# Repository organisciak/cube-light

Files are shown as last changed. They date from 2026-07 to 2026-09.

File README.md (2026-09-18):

# cube-light

**A 10×10×10 music reactive LED cube.** One thousand addressable pixels, an
ESP32 microcontroller that lives inside the cube, a phone-friendly console. And 3D snake!

Best way to understand it - try it in browser: <https://cube.porg.dev>

| | |
|---|---|
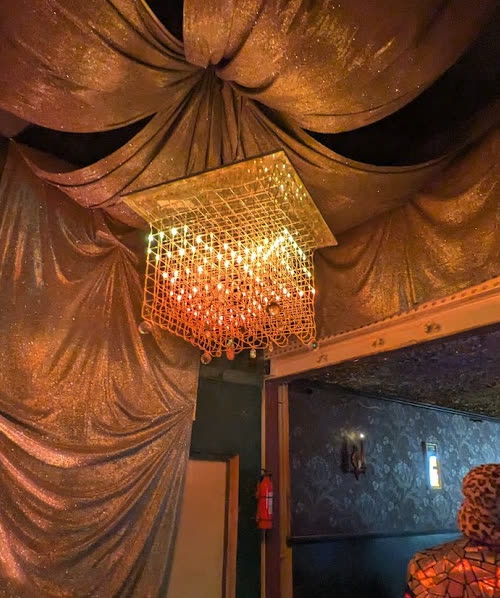
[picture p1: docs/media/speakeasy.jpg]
The cube hanging in the speakeasy
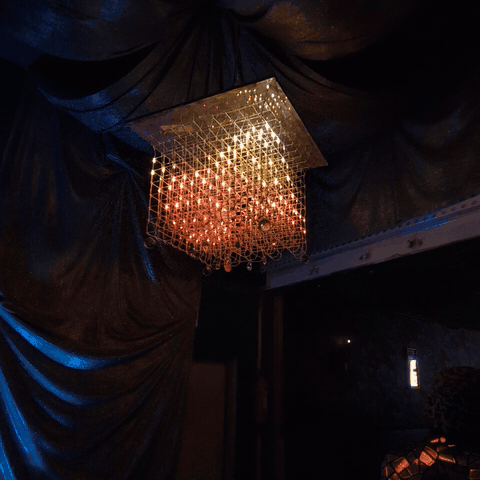
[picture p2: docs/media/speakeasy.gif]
The cube reacting to music in the speakeasy
|  |  |

It went to the playa in 2026 and ran for a week off in our camp's [speakeasy](https://www.instagram.com/p/DdFiTw2u4o9/).
[Here's a minute of it](docs/media/cube-light-playa.mp4) lit up at home and mid-build.
This repo is everything needed to build one: the firmware, the console, the
calibration tools, and (soon) the physical build notes. The firmware is all custom, which allows much more interesting music-reactivity and varied patterning.

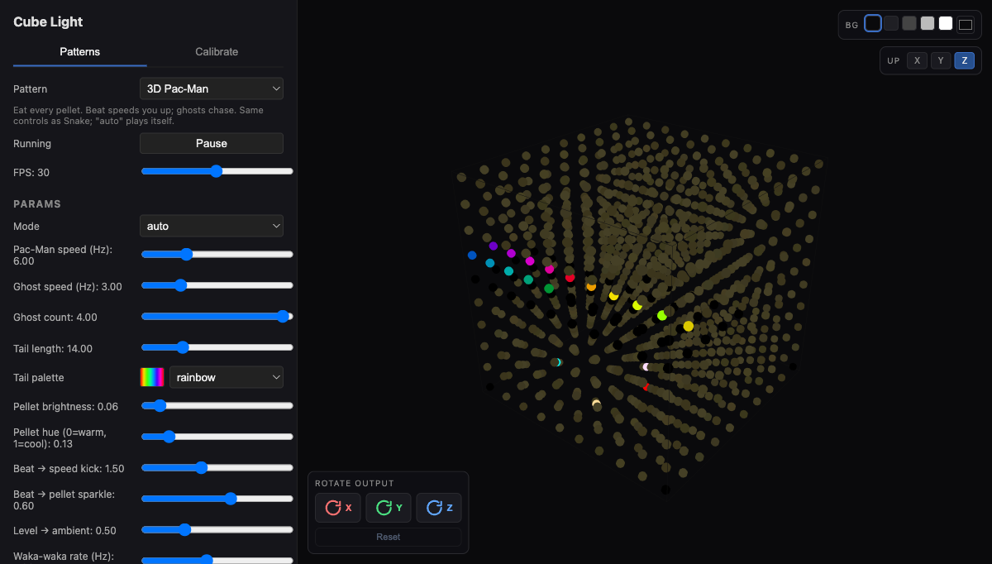
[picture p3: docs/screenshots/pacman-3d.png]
3D Pac-Man playing itself


## What it does

- **28 patterns** written against `(x, y, z)` voxels rather than a strip: wavy
  sheet, rotating planes, rain, comets, storm cloud, spirals, orbiting atoms,
  a tumbling wireframe cube, a first-person neon rail ride, a synesthetic
  tunnel, a double helix, TV static, fireworks, a 3D text marquee, album art
  on all four faces, and more.
- **Music-reactive.** An onboard mic feeds an FFT, eight log-spaced bands, a
  loudness envelope and a beat detector into every pattern. Patterns choose
  what to do with it: throb, spin faster, spawn ripples, kick the rail.
- **Games.** 3D Snake and 3D Pac-Man with a phone game pad (or they play
  themselves with a BFS solver when nobody is holding the controls).
- **Presets and playlists.** Save any pattern + params + palette as a preset,
  weight it, and let the cube cycle. Curated playlists, shuffle, a demo dwell
  for filming, and a physical button that steps to the next preset.
- **Guest mode.** Anyone who joins the cube's hotspot gets patterns, knobs,
  brightness and the game pad. Settings, Wi-Fi and calibration stay behind an
  owner password. Flip one switch and the hotspot password is the only gate.
- **Home Assistant.** MQTT discovery publishes a light, pattern and preset
  selects, playlist transport, and a text entity. Song titles and album art
  from your media player show up on the cube. See
  [docs/home-assistant.md](docs/home-assistant.md).
- **Per-parameter modulation.** Any numeric knob can ride an LFO or a random
  walk, so a static preset keeps evolving.
- **Calibration that solves your wiring.** Light one LED, say where it is,
  repeat a few times; the cube works out axis order, flips and serpentine
  runs from 192 candidate layouts. Snipped-LED compensation keeps geometry
  correct after you cut a dead pixel out of a chain.
- **Runs on ~$20 of controller.** A Gledopto WLED controller straight out of
  the box, or any classic ESP32 plus an I2S microphone.

| | |
|---|---|
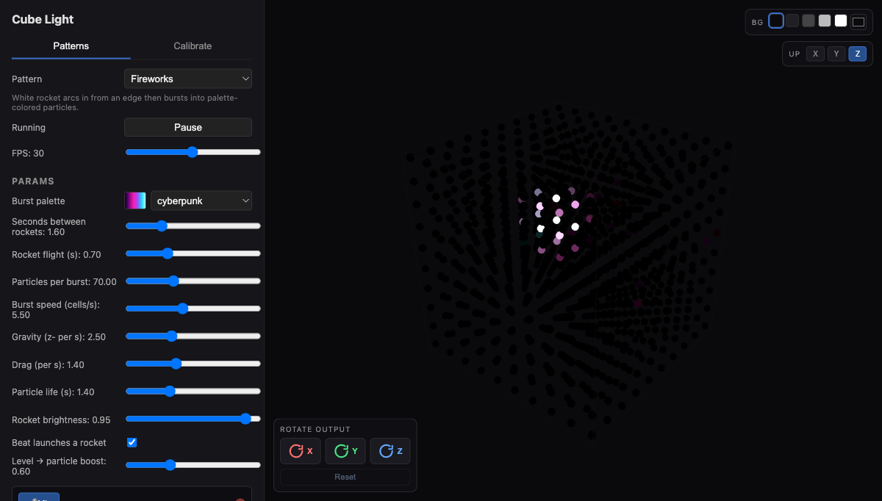
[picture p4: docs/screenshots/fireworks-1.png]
Fireworks
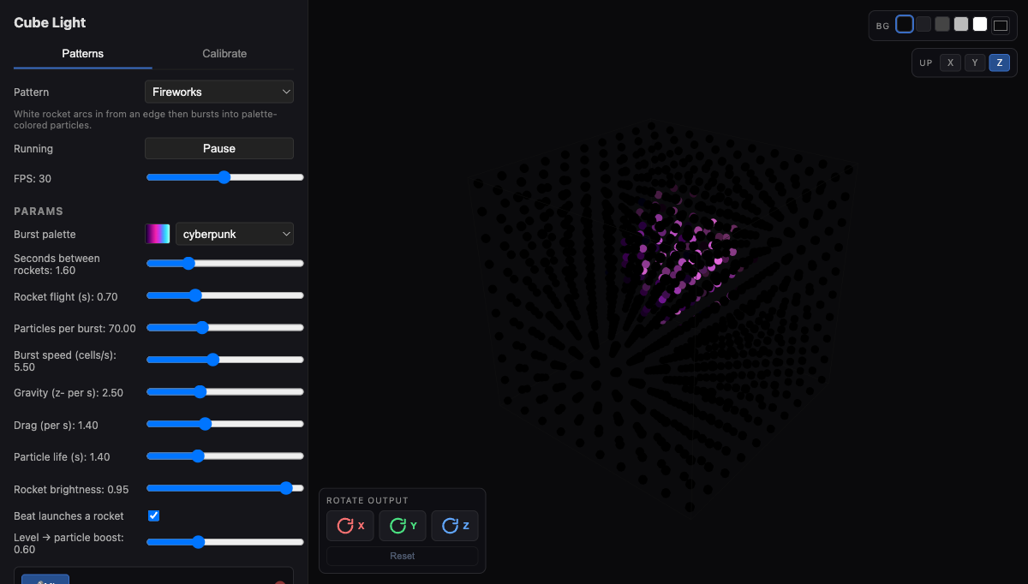
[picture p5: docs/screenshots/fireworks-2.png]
Fireworks, cyberpunk palette
|  |  |
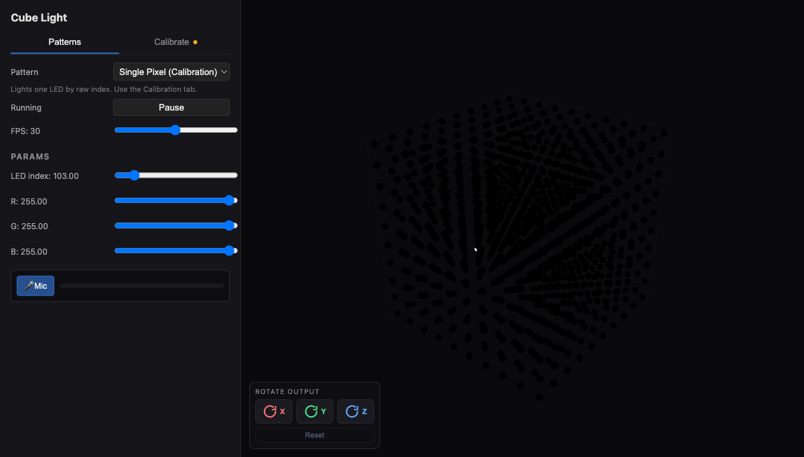
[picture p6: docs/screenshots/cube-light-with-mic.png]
Calibration lighting one LED
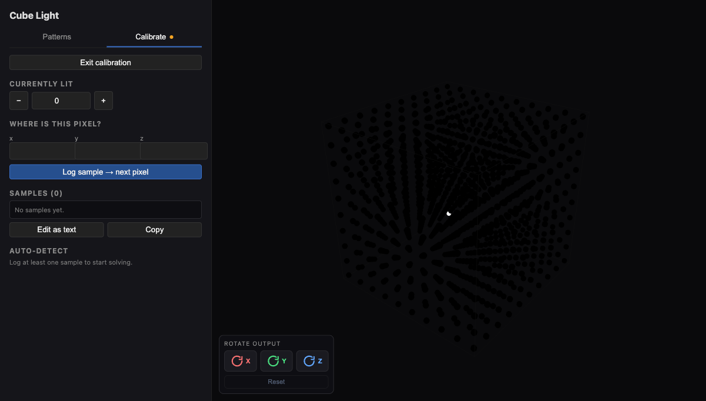
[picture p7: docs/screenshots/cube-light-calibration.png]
Calibration samples
|  |  |

*Screenshots are from the retired browser preview. For the real thing without
a cube, the [browser simulator](https://cube.porg.dev/) runs the
firmware's own pattern code (compiled to WebAssembly) and draws it like a
1984 CRT logo card.*

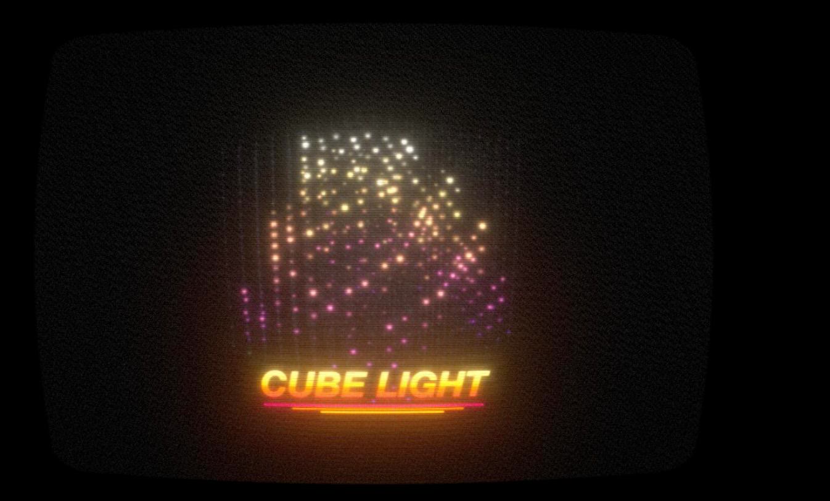
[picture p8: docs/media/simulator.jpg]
The simulator: firmware patterns through a CRT shader


## Building one

Three parts: a cube of LEDs, a controller, and this firmware.

### 1. The cube

- **1000 × 12 V WS2811 "seed" pixels**, wired as two chains of 500. Seed
  pixels (the tiny ones on thin wire, not 12 mm bullets) matter: the cube
  reads as points of light in air rather than a wall of bulbs. These are
  [the RGB ones I used](https://www.aliexpress.us/item/3256807315916397.html);
  BTF-Lighting, Ray Wu and the usual AliExpress storefronts all sell similar
  1000-pixel strings under *WS2811 12V seed pixel string*.

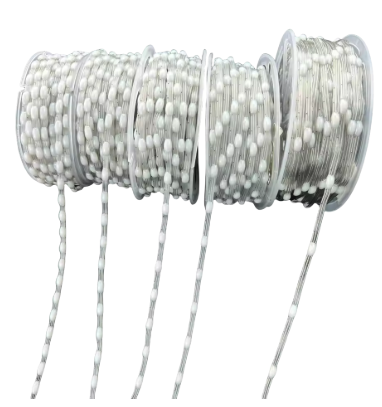
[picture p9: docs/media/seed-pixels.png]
WS2811 seed pixel strings on reels
  

    - Almost certainly, SK6812-style lights with their own white (RGBW) would look better, for a bit more money - here's a listing of ones I've used elsewhere [https://www.aliexpress.us/item/3256805834823384.html]. I haven't tried it with my cube light build, though.
    - If you wanted to do 5V instead of 12V, you'd probably get power dropoff with two runs of 500 leds. Easy enough - just have power injection more frequently. The code would need (tiny) modification if you wanted more than two data lines, though.
- A frame that holds 10 vertical strings of 100 pixels each in a 10×10 grid. Any wiring order works because calibration solves it afterwards. I ran it as a long snake that would go top down on one column, then bottom up on the next, etc. This required a bit of code calibration, because the first pixel of the run was at 0,0,0, but the second pixel is 0,0,1, while 0,1,0 was the 10th pixel and 1,0,0 was the 200th. 
    - What didn't work well: version one had two acrylic sheets - top and bottom plane, with holes drilled out and the lights strung through. I'd hoped the weight of the bottom sheet would pull everything down. However, getting the wires taut in between was tricky, and everything looked sloppy.
    - What *did* work: 3D-printed clips, keeping all the planes connected. STLs, OpenSCAD source and print notes are in [`hardware/clips/`](hardware/clips/). I used translucent PETG and the scaffolding clips both kept the shape and didn't obscure the lights, complemented the design with a matrix look.
- A 12 V supply. The firmware's power limiter caps total draw (default 10 A); full white on 1000 pixels would be ~15 A, so the software limiter matters (or just get a big boy supply!).

Build notes, photos and the parts list are in
[docs/build.md](docs/build.md).

### 2. The controller

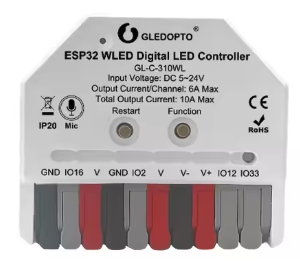
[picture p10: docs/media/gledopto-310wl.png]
Gledopto GL-C-310WL


| Board | Mic | Flashing | Notes |
| --- | --- | --- | --- |
| **Gledopto GL-C-618WL** | onboard PDM | USB-C | The board the project was developed on. This is just a nice enclosure for an ESP-32 with mic and all the things you probably would neglect otherwise (fuse, power relay, step-up). This specific model was probably overkill - don't need the ethernet. Slightly smaller ones that would work from the same company are: GL-C-017WL-D (015 or 016 too) or the GL-C-615WL. I wouldn't expect an ESP8266 to work, I pushed this one pretty far. |
| Gledopto GL-C-310WL | onboard I2S | OTA only (no USB) | Mini version. These are just great to have around for various projects. Don't do the 309, which is mic-less - and the cube is not as exciting without one. I brought a backup to playa on a 309 without realizing it was the wrong one, glad I didn't have to use it! |
| Any ESP32 + INMP441 | I2S | USB | Wire your own; pins are build flags. |

Every board is one `[env:...]` block in
[firmware/platformio.ini](firmware/platformio.ini): LED pins, button, relay,
mic type and pins, mDNS name. Copy one and edit for new hardware.

### 3. The firmware

```bash
cd firmware
pio run -e gledopto618 -t upload      # first flash over USB
pio device monitor -e gledopto618     # 115200 baud
```

The cube comes up as a Wi-Fi hotspot named `cube-light` (password
`cubelight`, change it). Join it, open <http://cube.local/> or
<http://192.168.4.1/>, and pick a pattern. The `/wifi` page joins it to your
home network; after that, wireless updates are available from `/admin`.

No-USB boards (309/310) get their first image through stock WLED's update
page. [docs/flashing-offline.md](docs/flashing-offline.md) is the full
runbook, including recovery and the OTA size ceiling.

## The console

Everything is served from the cube itself, sized for a phone.

- `/` picks patterns (grouped into light patterns, games, and tools), exposes
  each pattern's parameters with hover help, palettes, brightness, the mic
  toggle, the preset sidebar and the playlist transport. Advanced mode reveals
  modulation and the audio-drive caps.
- `/snake` is the game pad. Direction keys are calibrated to the player's
  viewpoint so "up" means up from where you stand.
- `/admin` handles power, wireless update arming, presets import/export and
  the demo dwell. `/leds` sets outputs, color order, snipped-LED compensation
  and the mic channel/squelch. `/calibrate` runs the wiring wizard. `/wifi`
  holds network, passwords, guest mode and the Home Assistant broker.
- `/api/status`, `/api/audio` and friends are plain JSON if you want to
  script it. DNRGB packets on udp/21324 (WLED's realtime protocol) override
  the local pattern, so anything that can drive WLED can drive the cube.

## Running the engine on your computer

The pattern engine is dependency-free C++ shared between the ESP32 build and
a native harness:

```bash
firmware/native/build.sh
firmware/native/build/cube-native rez-tunnel --fake-audio --host 192.168.0.180
```

It streams DNRGB frames to a cube, to stock WLED, or to any receiver that
speaks the protocol. See [firmware/README.md](firmware/README.md) for the
engine layout and how to add a pattern.

## Simulator

**Live at [cube.porg.dev](https://cube.porg.dev/).**
[`simulator/`](simulator/) is the cube in a browser tab: the firmware engine
compiled to WebAssembly, rendered in three.js with phosphor persistence, bloom
and a full CRT pass (scanlines, grille, curvature, aberration, bleed, grain).
Your laptop mic drives the music-reactive patterns through the same band
analysis and beat detector the cube uses, or a synthetic 120 BPM groove does.
It records 5 or 10 second WebM clips, because LED cubes photograph terribly.

```bash
python3 simulator/serve.py   # then open http://127.0.0.1:5277/
```

## Roadmap

- **Build documentation** with more photos and a finished bill of materials.
- ESP-NOW hardware controller for Snake ([docs/controller-plan.md](docs/controller-plan.md)).

Open issues live in the repo's `.beads/` tracker.

## Repo layout

- `firmware/lib/core/` — the pattern engine (pure C++): geometry, palettes,
  params, audio analysis, one file per pattern.
- `firmware/src/` — ESP32 glue: networking, web console, mic capture, presets,
  Home Assistant.
- `firmware/native/` — host harness.
- `hardware/clips/` — the 3D-printed frame clips (STL + OpenSCAD).
- `simulator/` — browser simulator: the engine as WASM + three.js CRT renderer.
- `docs/` — flashing runbook, HA integration, build notes, stock-WLED config
  backups for the boards, screenshots.

The original React + Node prototype that streamed frames to stock WLED is
preserved at git tag `wled-prototype` - once I moved away from that prototyping code, I never looked back, so treat it with a grain of salt.

## License

MIT. See [LICENSE](LICENSE).

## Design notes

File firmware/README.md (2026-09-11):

# cube-light firmware

Standalone brain for the cube: the pattern engine running on the Gledopto
ESP32 itself (GL-C-618WL target). See `docs/on-chip-plan.md` for the full plan.

## Layout

- `lib/core/` — the pattern engine, **pure C++** (no Arduino headers):
  geometry, palettes, color, params, audio analysis, and the patterns
  themselves. Compiles identically for the ESP32 and for the host.
- `src/main.cpp` — ESP32 entry point: WiFi, NeoPixelBus (RMT) LED output,
  DNRGB live-override listener on udp/21324, ArduinoOTA. Pins come from
  `platformio.ini` build flags — check them against stock WLED's settings
  for any new board before first flash.
- `native/` — host harness. Compiles `lib/core` with clang++ and streams
  frames as WLED DNRGB packets, so the exact firmware pattern code can be
  run with zero hardware (point it at a real cube, stock WLED, or a
  DNRGB-speaking simulator).
- `platformio.ini` — ESP32 build config (`pio run -e gledopto618 -t upload`).
- `src/ha_mqtt.h` — Home Assistant bridge (MQTT discovery: light + pattern /
  preset selects + text entity). Configure from `/wifi`; see
  `docs/home-assistant.md` for automations (song titles, album art).

## Running the engine without hardware

```bash
firmware/native/build.sh
firmware/native/build/cube-native wavy-sheet --fake-audio --host 192.168.0.180
```

The harness renders the exact firmware pattern code on your machine and sends
DNRGB packets (udp/21324) to `--host` (default `127.0.0.1`). Any DNRGB receiver
works: a cube running this firmware (its live-override listener takes the
frames), stock WLED with *Receive UDP realtime* on, or a simulator. A
browser-based simulator that receives these frames is planned (see the beads
issue tracker); the retired React preview that used to fill this role lives at
git tag `wled-prototype`.

Harness usage:

```
cube-native [patternId] [key=value ...] [--fps N] [--seconds S] [--fake-audio]
            [--host IP] [--port P]
```

`key=value` pairs map to the pattern's params (`true`/`false` → bool, numbers
→ number, else string), e.g. `cube-native wavy-sheet palette=arctic amp=2`.
Unset params use the defaults from `cube_param_specs.h`.

Caveat: the harness renders with the **default layout**; a receiver with a
calibrated layout active will look scrambled.

## Adding a pattern

1. Copy the closest `pat_*.cpp` and write the render body against
   `PatternCtx` (`cube_pattern.h`): `t`, `dt`, `audio`, `params`, and the
   `setIdx(x,y,z)` voxel index. Params are read with inline defaults
   (`p.num("amp", 1.2f)`).
2. Register it in `cube_patterns.cpp` and add its spec block to
   `cube_param_specs.h` (that block drives the web UI's controls).
3. `firmware/native/build.sh && cube-native <id> --fake-audio` against a cube
   or simulator, then an on-cube pass — LED cubes read very differently from
   a screen (sparse, high-contrast designs win).

### Pattern param specs

`lib/core/cube_param_specs.h` (parameter names/types/ranges/defaults for the
web UI) is **hand-maintained and authoritative** — edit it directly when
adding or changing a pattern's params.

Two shared blocks get spliced into pattern spec arrays instead of being
retyped, so the same knob means the same thing everywhere:

- `CUBE_THROB_SPECS(defaultDepth)` — the beat-driven brightness throb
  (`cube_throb.h`): `throbDepth` / `throbAttack` / `throbRelease`.
- `CUBE_PALETTE_SOLO_SPECS` — single-color palette mode (`cube_palettes.h`):
  `paletteSolo` / `soloSpeed`. On every pattern that has a `palette` param.

### Single-color ("solo") palettes

With `paletteSolo` on, a palette stops being a spatial gradient and becomes a
journey: the whole pattern takes **one** palette color per frame and drifts
through the palette at `soloSpeed` passes/second. Picking `rainbow` walks the
cube through the colors of the rainbow one at a time; `fire` walks red →
orange → yellow → white and back.

It lives in the palette layer — `resolvePalette(name, params, now)` bakes the
drifting position into the `PaletteRef` and `samplePalette()` ignores the
per-voxel `t` — so every palette-bearing pattern gets it for free. Sampled
colors are renormalized to full value in this mode, since most gradients ramp
out of black and a solo sweep through that end would just dim the cube.

## Snipped-LED compensation

Burnt-out LEDs get physically cut off a chain; without compensation, a snip at
the *start* of an output shifts every surviving LED's data by that many
positions and scrambles the calibrated geometry. The `/leds` page (and
`/api/ledcfg` args `skip1/trim1/skip2/trim2`, persisted in NVS) records how
many LEDs each output lost from its start/end: `show()` then feeds each data
slot the logical LED that physically sits there, so patterns stay
geometry-correct and the snipped spots simply go dark. End trims are recorded
for completeness but need no shift.

To rehearse on an intact cube, the same page has a snip **simulator**
(`/api/ledsim`, runtime-only — reboot clears it): it makes a chain behave as
if N LEDs were cut. Simulate N, watch the pattern slide out of place, set
"snipped from start" to N, and it should snap back with N dark spots.

## Hardware gotchas (learned the hard way)

- **Arduino core 2.x WiFi crash-loop on mesh networks.** The stock PlatformIO
  `espressif32` platform is frozen at arduino-esp32 2.x (IDF 4.4), whose WiFi
  stack dies with `InstructionFetchError` in `sta_recv_mgmt` /
  `offchan_recv_action` when a router sends 802.11k/v roaming action frames —
  i.e., the instant it joins a mesh network as a client. AP mode never
  triggers it (nobody sends the cube those frames), which made it look like
  "joining WiFi broke the cube." Fixed by the pioarduino platform pin in
  platformio.ini (arduino-esp32 3.x / IDF 5.5).
- **Startup ordering matters.** Network services (mDNS/OTA/UDP/HTTP) and the
  mic start from `startNetServices()` only after an interface is up.
- **GPIO18 relay must be HIGH** or the LED string has no power (looks exactly
  like a data-wiring failure).
- Debug flags for bisecting on-hardware problems:
  `-DCUBE_LED_BISECT_DISABLE`, `-DCUBE_MIC_BISECT_NO_I2S`,
  `-DCUBE_MIC_BISECT_NO_TASK`.

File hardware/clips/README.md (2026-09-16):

# Frame clips (3D-printed)

The original cube used the weight of the hanging strings and a bottom clear acrylic plate to keep the planes aligned - it didn't work well.

The improvement was to 3D print translucent combs of spaced clips to add a matrix scaffolding to the cube.
Each comb is a thin bar with a snap clip every 50 mm; the clips grab the string's wire between beads, and the beads themselves
(bigger than any pocket) act as position stops. Stack combs across rows and
columns and the strings hold each other square. Translucent PETG nearly
vanishes when the cube is lit, and what you do see reads as a matrix scaffold.

The combs had either 5 or 6 clips on them - my 3d printer (nor most?) doesn't have a bed big enough to print a single comb that spans the full cube widths, so instead I had LEDs 1-5 clipped, then 5-10.

| File | Clips | Length | Shape |
| --- | --- | --- | --- |
| `strut-u24.stl` | 5 | 204 mm | U: pockets open sideways off the bar |
| `strut-c24.stl` | 5 | 210 mm | C: the bar is the lower jaw, a barbed finger closes over the wire |
| `strut6-u24.stl` | 6 | 254 mm | U, six clips |
| `strut6-c24.stl` | 6 | 260 mm | C, six clips |

All are 2.4 mm thick with a 1.1 mm pocket (sized for the squishy stranded
seed-pixel wire, 4.8 × 1.3 mm) and a 1.2 mm bar.

| U clip | C clip |
| --- | --- |
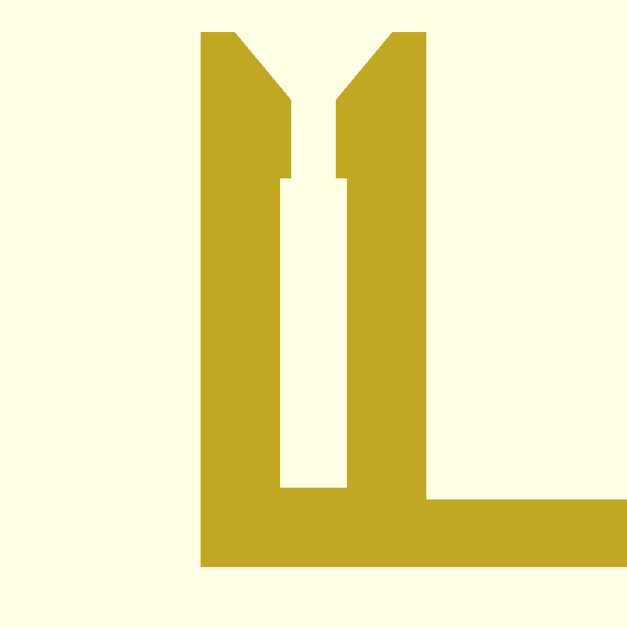
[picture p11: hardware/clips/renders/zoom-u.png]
U clip station
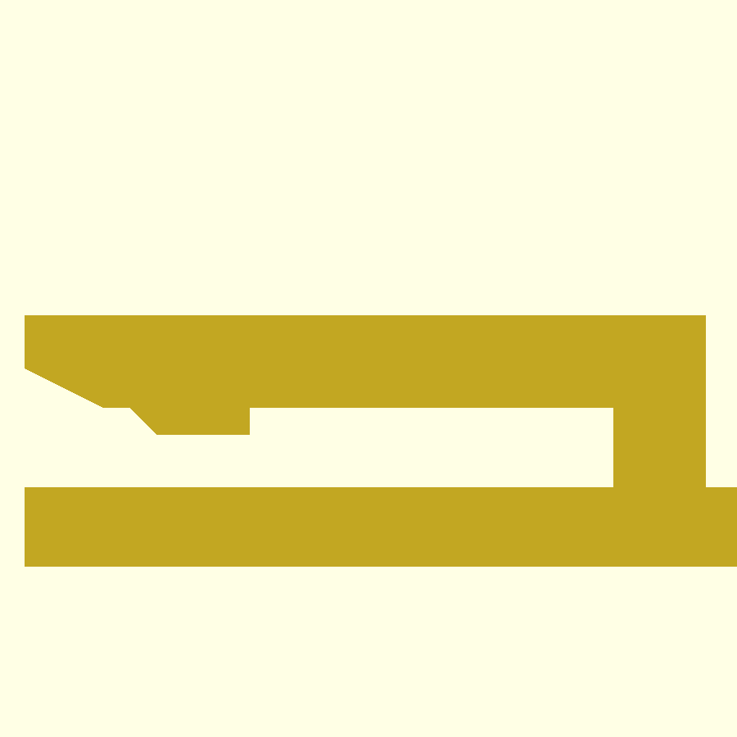
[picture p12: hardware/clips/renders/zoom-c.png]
C clip station
|  |  |

## U or C?

Both grab the same wire; they differ in how they load and hold.

- **U** pockets sit beside the bar. Push each wire down into its funnel and it
  clicks past the throat. Easy to load one wire at a time.
- **C** clips lie along the bar, so the whole comb loads in one move: slide it
  about 8 mm along its own axis and all the wires click under the barbs at
  once. The catch is that a comb whose clips all open one way can also slide
  *off* that way. The OpenSCAD source has an `alt=true` option that mirrors
  every second clip so the wires lock it on, at the cost of loading one wire
  per click. On the cube, plain C combs held fine for two weeks of use.

Mix freely: the 5- and 6-clip lengths cover a 10-wide grid in two pieces.

## Printing

- Print **flat as modelled**, no supports. The snap flex has to be in the
  layer plane; printed upright, the fingers would split along layer lines.
- **0.2 mm layers** (the 2.4 mm height is exactly 12 layers). 0.4 mm nozzle.
- **PETG** for the real cube (repeated snap flexing; PLA gets brittle).
  255 °C nozzle, 70 °C bed, 3 walls, brim on.
- **The 6-clip combs only fit a 256 mm bed diagonally.** Rotate 45° in the
  slicer. A bar offset *d* mm from the plate diagonal has 362 − 2*d* mm of
  room, so roughly 15 C combs or 9 U combs fit one plate.
- Handle the bars gently coming off the bed; they are long, thin blades.

## Regenerating

`comb-lib.scad` holds the clip geometry, `strut-set.scad` the comb layouts.
Everything is a parameter: pocket width (`slot`), thickness, clip count,
pitch. For a different wire, print `strut2-*` coupons first (two clips, minutes
each) and step `slot` by 0.1 mm at a time.

```bash
openscad --export-format binstl -o strut-c24.stl -D 'part="c24"' strut-set.scad
openscad --export-format binstl -o strut6-u24.stl -D 'part="u24"' -D n_clips=6 strut-set.scad
openscad --export-format binstl -o strut6-c24-alt.stl -D 'part="c24"' -D n_clips=6 -D alt=true strut-set.scad
```

Other thicknesses from the same source (`part` = `u06` … `u32`, `c06` … `c32`)
were a sweep for preference; thinner combs are nearly invisible but flex more.
2.4 mm is the tested production choice.

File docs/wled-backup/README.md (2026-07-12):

# Stock WLED backup — GL-C-618WL ("cube2-temp"), 2026-07-12

Snapshot of the factory WLED 0.15.3 config before flashing custom firmware.
`cfg.json` is the authoritative machine-readable backup (restorable via
WLED's settings → Security & Updates → restore). Screenshots are the
human-readable copy.

## Pin map (from cfg.json — the board's de-facto schematic)

| function | GPIO | notes |
|---|---|---|
| LED output 1 | 16 | factory: 4 outputs × 30 LEDs, type WS281x |
| LED output 2 | 12 | |
| LED output 3 | 4  | |
| LED output 4 | 2  | |
| Function button | 17 | push, active-low, internal pullup |
| **Relay (LED power)** | **18** | active high — **must be driven HIGH or the string is dark** |
| Mic (I2S PDM) | DATA=32, CLK=15 | AudioReactive "digitalmic" type 5 |
| IR | — | disabled |
| Ethernet | type 13; pins 21/19/22/25/26/27/5/23/33/0 | unused by our firmware |

Other factory settings of note:

- Color order: 0 = **GRB**
- ABL: maxpwr 850mA (factory default, not our PSU's real budget)
- AudioReactive usermod enabled: squelch 4, gain 60, AGC 2, freq scale 3
- USB-UART chip: WCH CH340-family, VID 0x1A86 PID 0x7522 (needs WCH's
  CH34x VCP driver on macOS; Apple's built-in driver doesn't cover this PID)

## Files

- `cfg.json` — full WLED config (the restore file)
- `presets.json` — presets (factory-empty)
- `info.json` — /json/info snapshot (version, arch)
- `settings-{leds,sync,um,wifi,sec}.png` — settings pages

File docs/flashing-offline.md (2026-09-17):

# Flashing the cube offline

Everything here works with no internet: the toolchain, the ESP32 platform, and
both prebuilt images are already on this laptop. Written 2026-08-29 on playa.

Prebuilt images live in `firmware/release/`:

| file | board | how it goes on |
| --- | --- | --- |
| `cube-618-2026-08-29.bin` | GL-C-618WL (main) | USB, or armed OTA |
| `cube-618-2026-08-29.factory.bin` | GL-C-618WL (main) | USB only — bootloader + table + app, for a full rebuild at 0x0 |
| `cube-309-2026-08-29.bin` | GL-C-309WL (backup, no USB) | OTA only |

Rebuild either from source with `pio run -e gledopto618` / `-e gledopto309`
(from `firmware/`). Output lands in `.pio/build/<env>/firmware.bin`.

## Linux serial-port access (one-time)

This machine is not set up for serial yet — that's why nothing seemed to
happen when the board was plugged in. Linux has no "allow this device?"
popup like macOS; access is a Unix group instead. The board *is* detected:
a CH340 USB-serial converter at `/dev/ttyUSB0`, owned `root:dialout`, mode
`0660`. The user account is not in `dialout`, so opening the port fails with
`Permission denied`.

```bash
sudo usermod -aG dialout $USER   # permanent — takes effect at next login
sudo chown $USER /dev/ttyUSB0    # takes effect NOW, until the board is unplugged
```

Run both: the first is the real fix, the second avoids logging out mid-session.
Re-run the `chown` after every replug until you have logged out and back in.

Confirm the board is there:

```bash
lsusb | grep -i ch340          # QinHeng Electronics CH340 serial converter
ls -l /dev/ttyUSB0
```

## Flashing the 618 over USB

```bash
cd ~/projects/cube-light/firmware
pio run -e gledopto618 -t upload --upload-port /dev/ttyUSB0
pio device monitor -e gledopto618 --port /dev/ttyUSB0   # 115200; ctrl-] to quit
```

A serial upload writes bootloader + partition table + app. It does **not**
full-erase, and `partitions_cube.csv` keeps NVS at the stock 0x9000/0x5000, so
every saved setting survives: Wi-Fi credentials, AP/console passwords,
per-pattern params, up-axis, LED and mic config, calibration.

### Back up the existing flash first (optional, ~2 min)

```bash
cd ~/projects/cube-light/firmware
~/.platformio/penv/bin/esptool --port /dev/ttyUSB0 --baud 460800 \
    read-flash 0 0x400000 release/618-flash-backup-$(date +%F).bin
```

Restore that image with:

```bash
~/.platformio/penv/bin/esptool --port /dev/ttyUSB0 --baud 460800 \
    write-flash 0 release/618-flash-backup-YYYY-MM-DD.bin
```

### If a flash goes wrong

You cannot brick an ESP32 this way. The first-stage bootloader lives in mask
ROM and cannot be overwritten. Hold the function/BOOT button while plugging
the board in to force download mode, then flash anything — including stock
WLED from `docs/wled-backup/`.

## Updating the 309 (backup board) with no USB

The 309 has no USB port. OTA is the only path, and it is deliberately gated.
Order matters:

1. **Set a non-default AP password.** Open `/wifi` and change it from the
   factory `cubelight`. `/api/ota` refuses to arm while the AP password is
   still the factory default, and OTA reuses the AP password as its own.
2. **Arm the window.** On `/admin`, open the wireless-update window. It lasts
   15 minutes, re-arms on request, and closes on any reboot.
3. **Push the image** within that window:

```bash
python3 ~/.platformio/packages/framework-arduinoespressif32/tools/espota.py \
    -i cube2.local -p 3232 --auth=YOUR_AP_PASSWORD \
    -f ~/projects/cube-light/firmware/release/cube-309-2026-08-29.bin
```

Use the board's IP instead of `cube2.local` if mDNS is not resolving.

**Size ceiling.** The 309 keeps stock WLED's partition table forever — OTA
replaces an app, it cannot redraw the map. Its app slot is 1.5 MB, versus the
618's custom 1.875 MB. `env:gledopto309` builds against
`partitions_wled_4mb.csv` so the size check fails loudly rather than producing
an image that bricks the board on first boot. Today's build uses 90.4% of that
slot (1421441 of 1572864 bytes) — real headroom, but thin. Check that number
on every 309 build.

**Only ever OTA an image already proven on the 618.** Recovery from a bad
image on the 309 means opening the case and soldering to the serial pads.

## Getting into /admin when there is no home Wi-Fi

Away from the home network the cube falls back to its own AP. Anyone on that
AP subnet is treated as a guest, and guests do not get owner settings.

Log in as username **`cube`**. The password is the console password if one is
set, otherwise the cube's own Wi-Fi (AP) password. The browser prompts for it
when you open `/admin`, `/leds`, `/calibrate` or `/wifi`.

The fallback to the AP password exists so an owner on the fallback AP always
has *some* credential to offer. It is a speed bump, not a secret — everyone on
the AP typed that password to join. Set a real console password from `/wifi`
before handing the cube to a crowd.

## Returning a no-USB board to stock WLED

Done 2026-09-16 on the 309. The same armed-OTA path takes a plain WLED app
image, because the board never left WLED's factory partition table:

1. Download the official release for the chip (`WLED_<ver>_ESP32.bin`, from
   the WLED GitHub releases) and check it is under the 1.5 MB slot.
2. Arm the window: `curl -u cube:<pass> -X POST http://<cube>/api/ota?on=1`.
3. `espota.py -i <ip> -p 3232 --auth=<AP pass> -f WLED_<ver>_ESP32.bin -r`.
4. Poll `http://<ip>/json/info`. WLED's own `cfg.json` on the flash
   filesystem survives alongside the cube firmware's preset files, so the
   board came back with its old Wi-Fi, LED and pin settings intact. If it
   hadn't, it would appear as the `WLED-AP` hotspot (password `wled1234`)
   for the config to be restored from `docs/wled-backup-*/cfg.json`.

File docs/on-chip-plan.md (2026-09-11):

> **Historical.** This was the plan for moving the pattern engine from the
> React/Node prototype onto the ESP32. That port is complete and the prototype
> was retired (git tag `wled-prototype`). Kept for the hardware reasoning and
> the design rationale; paths and workflow described below no longer exist.

# Porting cube-light to the chip

**Goal:** the pattern brain runs standalone on the Gledopto ESP32 — no laptop, no
separate computer — using the controller's onboard mic for audio reactivity. The
web app survives as the *development* environment (author patterns in TS with the
3D preview, then port), and optionally as a remote control when a phone is around.

Must-have patterns on-chip: **wavySheet** and **snake3d** (with a way for a third
party to control the snake). Everything else is gravy, ported in order of taste.

## Why not a WLED usermod

WLED's effect API is 1D/2D-shaped: effects iterate pixels in strip order, params
are a handful of 0–255 sliders, and stateful patterns (snake, particles) fight the
per-pixel model. Custom firmware costs us WLED's UI/ecosystem but our patterns port
almost mechanically — they're already `(t, dt, audio, params) → write buffer`
against an `(x,y,z)` index function. Custom firmware is the call. We keep two
WLED-compatible behaviors so the dev workflow survives: a DNRGB listener on 21324
(live frames from the dev server override the local pattern) and an HTTP firmware
upload endpoint (so we can always re-flash, including back to stock WLED).

## Hardware decision

### Dev and primary target: GL-C-618WL ("the big boy")

You already own it, and it's the right unit on every axis:

- **USB-C for firmware download** → a bad flash is a 30-second recovery, never a
  brick. This is what makes it the dev board.
- Onboard PDM mic (WLED's audioreactive runs on it stock — so it demonstrably
  works for our purpose).
- 20A pluggable fuse, reverse-polarity protection, energy-saving relay, DC 5–24V
  input → it takes the 12V bead supply directly and powers its own ESP32. No
  power engineering needed.
- Ethernet + 4 outputs we don't need but don't mind.

**Recommendation: dev on the 618WL and deploy on the 618WL.** It's prebuilt,
fused, and recoverable — exactly what you want in a dusty box on the playa. The
310WL becomes the backup/second unit, not the primary.

### Secondary target: GL-C-310WL (mini)

- Same ESP32 (classic, WiFi + BT 4.2), onboard mic — but it's an **I2S digital
  mic** on SD=GPIO26, WS=GPIO5, SCK=GPIO21. LED data on GPIO16 (also 2, 12).
- **No USB.** Stock flashing is OTA through WLED's update page. If our firmware
  boots broken, there's no serial rescue without cracking the case and soldering
  to the module's pads (recoverable in the lab, not at an event).
- Ship to it **only after** the firmware is stable on the 618WL, and only with the
  self-rescue scheme below in place.

Making OTA-only safe (this is standard ESP32 practice, not exotic):

1. **Two OTA app partitions + rollback** (`CONFIG_BOOTLOADER_APP_ROLLBACK_ENABLE`):
   a new image must mark itself valid after boot (e.g. after WiFi comes up and the
   HTTP server answers); if it doesn't, the bootloader reverts to the previous
   image on next reset. A power-cycle undoes a bad flash automatically.
2. **Watchdog** so a hung render loop causes that reset rather than a wedge.
3. First install goes *through WLED's own OTA updater* (it accepts any .bin), which
   means our image must fit the existing WLED partition slot (~1.5MB on the stock
   4MB table) and link against the same partition layout. Fine for our firmware
   size; just don't change the partition table on the USB-less unit.
4. Keep the stock WLED .bin for this exact board on disk. Our firmware exposes
   `/update` (same idea as WLED's) so we can always walk back.

**Pre-flash ritual (both units):** before wiping WLED, open its settings UI and
record every pin mapping it shows (LED GPIO, mic pins, relay pin, button pin).
The stock config is the board's de-facto schematic. Screenshot it into `docs/`.

### The breadboard S3 option: skip it

Not needed — you own two real targets, and the S3 is actually a *worse* match:
the Gledoptos are classic ESP32, so S3-specific work (different I2S peripheral, no
Bluetooth Classic) wouldn't transfer. It would also drag in the power problem for
no benefit. For completeness, the answer to that problem: a **buck converter**
("DC-DC step-down module", e.g. Mini560 or LM2596, ~$2) drops 12V to 5V for a bare
dev board — that's the term you were reaching for — plus a 74AHCT125 to shift the
3.3V data line up to the 5V the WS2811 wants. The Gledopto has both built in,
which is precisely why the prebuilt is right for the playa.

## Firmware architecture

PlatformIO + Arduino-ESP32 (drop to ESP-IDF only if driver timing forces it).

```
firmware/
  src/
    main.cpp            // loop: tick patterns @ 30fps, output, service network
    patterns/           // ported patterns, same shape as TS
    geometry.{h,cpp}    // port of src/shared/geometry.ts (12 lines of math)
    orientation.{h,cpp} // 24-rotation post-transform
    palettes.{h,cpp}
    audio.{h,cpp}       // I2S/PDM mic → FFT → 8 bands + beat envelope
    net/
      api.{h,cpp}       // HTTP + WS, mirrors ServerToClient/ClientToServer JSON
      dnrgb.{h,cpp}     // UDP 21324 listener: live frames override local brain
      ota.{h,cpp}       // /update endpoint + rollback confirm
    store.{h,cpp}       // LittleFS: layout, presets, last pattern+params
```

Pattern interface mirrors the TS one so porting is a translation, not a redesign:

```cpp
struct PatternCtx {
  uint8_t* buffer;                 // NUM_LEDS*3 RGB
  uint16_t (*idx)(uint8_t,uint8_t,uint8_t);
  float t, dt;
  const AudioFrame& audio;         // level, bands[8], beat
  const Params& params;
};
```

- **LED output:** NeoPixelBus or FastLED via RMT. 1000 WS2811 at 30fps is
  comfortable; the known risk is WiFi vs. LED-timing contention — stress test in
  week one, tune task priorities if needed.
- **Audio (in scope from the start, per the goal):** 618WL = PDM mic, 310WL = I2S
  mic on GPIO26/5/21. Read via the ESP32 I2S peripheral, FFT with ESP-DSP or
  arduinoFFT, collapse to the same 8 bands + beat-envelope math currently in
  `server/index.ts`. WLED's audioreactive usermod is open source and runs on
  these exact boards — crib its mic-init code rather than rediscovering I2S
  quirks.
- **Geometry/orientation/palettes:** direct ports, all small. The 192-candidate
  calibration solver stays host-side; the firmware just accepts a resolved
  `Layout` via the API and persists it.
- **API:** ESPAsyncWebServer serving the same WS JSON contract as
  `server/index.ts`, so the existing React app can point at `cube.local` for
  control and preview. The firmware also serves a small static controller page
  (below) from LittleFS.

## Snake control (third-party device)

Two tiers:

1. **Phone as controller (do this one):** the firmware serves a self-contained
   D-pad page at `http://cube.local/snake` — six buttons sending `snakeInput`
   over the same WS. Zero extra hardware, works for any guest with a phone on the
   cube's network. At the playa the ESP32 runs as its own WiFi AP (`cube-light`,
   no internet needed); anyone joins and plays. ~150 lines of HTML total.
2. **Bluetooth gamepad (stretch):** classic ESP32 does Bluetooth, and Bluepad32
   pairs PS4/Xbox/8BitDo pads directly. Caveat: WiFi+BT coexistence costs RAM and
   can jitter LED timing — prototype only after tier 1 works, and be ready to
   drop it. A BLE-only pad (8BitDo in BLE mode) coexists better than BT Classic.

## Development workflow after the port

The web stack stays, repurposed:

- **Authoring:** write/tune a pattern in TS against the Vite preview exactly as
  today, with the Node server sending DNRGB to the cube. The firmware yields to
  live packets automatically, so "dev mode" needs no mode switch on the cube.
- **Porting:** translate the finished TS pattern to C++ (mechanical for the pure-
  math ones). Flash over USB (618WL) or OTA.
- **Remote control:** the React app pointed at `cube.local` manages the on-chip
  brain — pattern select, params, presets, brightness — from any phone/laptop.

Yes, this means each shipped pattern exists twice (TS + C++). With no interpreter
on-chip that's the honest cost; the mirrored `PatternCtx` keeps the translation
diff-like. (A Pixelblaze-style on-chip script engine was considered and cut —
you said you don't need it, and it's the multi-month part.)

## Fallback considered: keep the brain external on a tiny computer

A Raspberry Pi Zero 2 W (~$20) runs the existing Node server unmodified, powered
from the same 12V through a USB buck adapter, and a phone can join its hotspot
for the React UI. Zero porting. It's a legitimate plan B — but it's a second
device, an SD card that can corrupt on hard power-loss, ~30s boot, and two things
to power and debug in the dust. The on-chip port is more work up front and much
more robust at the event. Going on-chip.

## Porting order

1. **Skeleton week (on the 618WL, USB attached):** WiFi + OTA + LittleFS + LED
   output + `wavySheet` ported + DNRGB listener. Success = cube runs wavy-sheet
   standalone at 30fps with no flicker, and the dev server can still take over.
2. **Audio:** mic → bands/beat, wire into wavySheet's audio distortion. Success =
   unplug everything, clap, cube reacts.
3. **API + persistence:** WS contract, params, presets, brightness, last-state
   restore on boot. React app controls the cube directly.
4. **snake3d + controller page.** BFS auto-solver ports as-is (1000-cell graph is
   nothing); manual mode via the D-pad page.
5. **Rest of the catalog by taste:** plasma, rotatingPlanes, fireworks (cap the
   particle pool), pacman3d, fire, rain, life3d, text3d…
6. **310WL bring-up (optional):** rollback partitions proven on the 618WL first,
   then OTA the mini, config-switch the pins (LED GPIO16, mic 26/5/21).

Step 1 is the go/no-go gate: if 1000 LEDs + WiFi hold 30fps on the Gledopto, the
rest is scheduled work, not research.

## Sources

- [GL-C-618WL product page](https://gledopto.com/h-pd-64.html) — PDM mic, USB-C
  program download, relay, fuse, DC 5–24V.
- [GL-C-618WL manual (PDF)](https://www.ledbe.com/image/catalog/gledopto/GL-C-618WL/Gledopto-ESP32-Elite-Advanced-WLED-Controller-User-Manual.pdf)
- [GL-C-309WL/310WL spec (PDF)](https://www.superlightingled.com/PDF/SPEC/GL-C-309WL+GL-C-310WL.pdf) —
  I2S mic pins SD=26 WS=5 SCK=21, LED GPIO16/2/12, 10A max.
- [WLED forum: Inside GLEDOPTO GL-C-310WL](https://wled.discourse.group/t/inside-gledopto-gl-c-310wl/15188) — teardown photos.
- [Gledopto WLED web flasher](https://gledopto.com/h-col-381.html) — stock
  firmware recovery images.

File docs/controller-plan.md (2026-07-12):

# Snake controller: a dedicated ESP32 remote

A second ESP32 with physical buttons in a 3D-printed case, talking to the
cube over **ESP-NOW**. Companion to `docs/on-chip-plan.md`.

## Why ESP-NOW (and not WiFi/Bluetooth)

ESP-NOW is Espressif's connectionless protocol at the WiFi MAC layer —
ESP-to-ESP directly, no router, no association, no TCP. Properties that
matter here:

- **Latency: 1–4ms** per packet. For comparison: joining the cube's AP and
  sending UDP is ~5–20ms plus reconnect stalls; Bluetooth Classic gamepads
  via Bluepad32 work but WiFi+BT coexistence on the ESP32 costs RAM and can
  jitter the LED timing.
- **Coexists with the cube's AP/STA mode** — the cube keeps serving its web
  page and receiving DNRGB while also receiving ESP-NOW.
- Controller can **deep-sleep** between play sessions and run months on a
  small battery.

## Will it be responsive enough?

Yes, with margin. The full chain:

| stage | time |
|---|---|
| debounce | ~5–10ms |
| ESP-NOW transmission | ~1–4ms |
| cube processes input (every `loop()` pass) | <1ms |
| **added latency total** | **~10–15ms** |
| game applies input at next tick (4–12Hz) | up to 83–250ms |

The game's own tick rate dominates by an order of magnitude — the snake
steps on a grid at 4–12Hz, so input feel is identical to a keyboard on the
dev setup. 10–15ms is also well under a single 30fps frame.

One design rule to make this true: the controller must **stay awake during
play**. Deep-sleep wake costs 100–300ms of boot, which WOULD be felt if it
happened per-press. So: wake on first press (that one press eats the boot
delay — acceptable, it's "picking up the controller"), stay awake while
buttons are active, deep-sleep after ~5 minutes idle.

## The 6-direction problem (and the fun answer)

3D snake needs six directions (x±, y±, z±). Layout options:

1. **Cube-shaped controller, one button per face.** Press the face the
   snake should go. Thematically perfect for a cube of cubes, dead-simple
   mapping, a great 3D-print. Downside: the face in your palm is awkward to
   press — mitigate by making it palm-sized and pressed like a fidget toy
   with both hands.
2. **Flat pad: D-pad cross (4) + two thumb buttons** for z± (like L/R
   shoulders). Most ergonomic, most conventional.
3. **Joystick module + 2 buttons.** Analog stick reads as 4 directions,
   buttons for z±. Fewer holes to print, slightly mushier feel.

Recommendation: build 2 (proven ergonomics) but seriously consider 1 for
the playa — guests understand it instantly with zero explanation.

Viewer-relative vs. cube-relative mapping: keep it cube-relative (buttons
map to cube axes) and rely on the existing direction-hint overlay (the
colored 3×3 flash on the face you pressed toward) to teach guests — it's
already in the firmware port.

## Hardware (≈ $10 total)

- **ESP32-C3 SuperMini** (~$3) — tiny (22×18mm), USB-C for flashing,
  ESP-NOW capable, deep-sleep friendly. Any ESP32 works; the C3 is the
  smallest cheap option.
- **6× 12mm tactile switches** (or Cherry MX–style for nicer feel; MX
  keycaps also print well).
- **LiPo 500mAh + TP4056 USB-C charge board** (~$2), or a 2×AAA holder if
  charging circuitry feels like overkill.
- Slide switch (hard power-off for transport), optional status LED.
- 3D-printed two-shell case; buttons wired to GPIOs with internal pullups,
  common ground. No other components needed — debounce is software.

## Protocol

One packet per press, broadcast (no pairing ceremony):

```
{ magic: 0xC0BE, seq: uint16, button: uint8 }   // button = SnakeDir 0..5
```

- Controller sends each press 3× at 5ms spacing (broadcast has no MAC-level
  ack); the cube dedupes on `seq`. Effectively lossless.
- Cube-side receive callback maps `button` straight to `queueSnakeInput()` /
  `queuePacmanInput()` (both already exist in `firmware/lib/core`), keyed on
  the active pattern.
- Later hardening: after first packet, cube can note the controller's MAC
  and the controller can switch to unicast (which does get MAC-level acks).

**The one real gotcha — WiFi channel.** ESP-NOW peers must be on the same
channel. When the cube runs its own AP (playa mode) the channel is pinned —
trivial. When the cube joins home WiFi, its channel follows the router, so
the controller boots by channel-scanning 1–11, sending a discovery ping on
each until the cube answers, then locks in. ~30 lines and a one-time
~200ms scan per controller boot.

## Software plan

1. `firmware/src/espnow_input.{h,cpp}` (cube side): init ESP-NOW alongside
   the existing WiFi mode, receive callback → validate magic → dedupe seq →
   queue input for the active game. ~60 lines.
2. `firmware/controller/` + a second PlatformIO env (`board = esp32-c3`):
   button scan + debounce, press → 3× broadcast, idle timer → deep sleep
   (EXT1 wake on any button), channel scan on boot. ~150 lines.
3. Case: OpenSCAD model once button layout is picked (option 1 or 2 above).

Testing needs two boards in hand — this is post-flash-day work. The
cube-side receive path can land earlier since it's inert without a sender.

## Alternatives already covered elsewhere

- **Phone D-pad page** (`/snake` on the cube's web server — planned): zero
  hardware, works for any guest, ~20–50ms latency over the AP. Do this
  regardless; the ESP-NOW remote is the premium tactile option on top.
- **BLE gamepad (8BitDo etc.) via Bluepad32**: stretch goal, watch RAM and
  LED-timing jitter from BT coexistence.
- **Wired buttons** into the 618WL's spare IOs (12/4/2/13): simplest
  possible, but a tethered controller is a tripping hazard in the dark.

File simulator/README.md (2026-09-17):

# Browser simulator

The firmware's pattern engine, running in your browser, drawn like a 1984
cathode-tube logo card. Live: <https://cube.porg.dev/>.

`firmware/lib/core` is dependency-free C++, so it compiles unchanged to
WebAssembly. The page loads that module, asks it for 1000 RGB values per frame,
and renders them with three.js through a CRT post-processing chain. Nothing in
`pat_*.cpp` is reimplemented in JavaScript: what you see is what the ESP32
computes, param specs and palettes included (they come out of the same headers
the console uses).

## Running it

It's static files. For local work use the bundled dev server (it disables
caching, which otherwise makes edits to the module scripts invisible):

```bash
python3 simulator/serve.py        # http://127.0.0.1:5277/
```

Hosting: the Vercel project `cube-light` is linked to this repo with root
directory `simulator/web` and no build step, so every push to `main` redeploys
<https://cube.porg.dev/>. `.github/workflows/pages.yml` can do the same
for GitHub Pages once Pages is enabled with "GitHub Actions" as the source.

- **Playlist**: on load the page cycles a playlist of presets, exactly as the
  cube does — each preset is a pattern plus params, dwell time and a
  music-reactive flag; reactive presets are skipped while audio is off, and
  picking a pattern by hand pauses the cycle. Shuffle (on by default) is the
  cube's weighted pick: each preset's chance is its priority, 0 never
  auto-plays, no immediate repeats. `web/presets.json` is the
  built-in list; *Import presets…* takes the cube's own export
  (`/api/presets/export` → `{"presets":[...]}`) and keeps it in localStorage.
  The wordmark shows the current preset's name unless you type your own;
  it can also be switched off, or set to burn out 2 s after each preset
  change (a bloom flash while it fades and swells). Game legends always show.
- **Onboarding**: a first-visit modal offers the microphone (the click is the
  user gesture WebAudio needs), sharing a tab with sound (Chrome/Edge), a
  synthetic beat, or silence; the choice is remembered.

- **Pattern** and its parameters: the same knobs as the cube's console.
  `#pattern-id` in the URL selects one on load.
- **Audio**: *tab / system audio* captures the clean digital feed of a tab
  that's playing music (pick it in the share dialog and tick *Share audio*;
  on Windows/ChromeOS the whole screen's audio works too), no room, no mic
  colouring, and recordings get it. *microphone* runs the firmware's band analysis (8 log-spaced
  bands, per-band floor/peak tracking) in WebAudio and feeds the bass band to
  the firmware's own `BeatDetector` (in the WASM) for beat and BPM. *Synthetic
  groove* is the native harness's fake audio: a 120 BPM pulse so reactive
  patterns move without a mic.
- **Emulator** (collapsed by default, saved in localStorage, with a
  reset): LED gain/size, neighbour spill (lit LEDs tint the unlit beads next
  to them), room light (an inside-out sphere and floor that take on the
  cube's mean colour, so a fully lit cube washes the tube and one pixel
  barely registers), bloom, phosphor persistence (a feedback buffer so
  bright voxels leave trails), and the CRT pass: luminance-dependent
  scanlines, aperture-grille mask, barrel curvature with rounded corners,
  chromatic aberration, horizontal beam bleed, vignette, grain, flicker, a
  rolling bar. Untick *CRT treatment* for a clean render.
- **Wordmark**: text under the cube in a block italic with sunset stripes, run
  through the same glow so the card reads like a broadcast ident.
- **Capture** (inside Emulator): a Frame selector letterboxes the canvas to
  portrait 9:16, square or 16:9 so recordings come out reel-shaped; Record
  (5, 10, 30 or 60 s, or stop early) saves a WebM from the canvas, with the microphone or tab audio
  mixed in when it's on; PNG saves a still.
- **Games**: arrow keys (X/Y) and W/S (Z). The wordmark under the cube
  becomes the legend; while you're driving, the orbit stops and the unlit
  beads brighten so the board reads. 12 s without a key hands the snake back
  to its solver.
- The slow orbit follows the beat: 120 BPM is the base rate, faster music
  spins faster, and each beat nudges it.

## Rebuilding the engine

Only needed when `firmware/lib/core` changes. Needs emscripten
(`brew install emscripten`):

```bash
simulator/build.sh     # -> simulator/web/engine.js + engine.wasm (commit them)
```

`wasm/bridge.cpp` is the whole C API: select pattern, set params, feed audio,
render a frame, read the buffer, plus JSON exports of the param specs and
palette names. Add a function there, and `build.sh` exports it automatically
(it greps the `EMSCRIPTEN_KEEPALIVE` names).

## Files

- `web/index.html`, `style.css` — the page and control panel.
- `web/app.js` — WASM loading, three.js scene (instanced billboard voxels with
  a soft-disc shader, the string lattice, the wordmark), controls, capture.
- `web/crt.js` — `PhosphorPass` and the `CRTShader` composite.
- `web/audio.js` — mic analysis mirroring `firmware/src/audio_capture.cpp`,
  and the synthetic groove.
- `web/engine.js`, `web/engine.wasm` — built output, committed.
- `wasm/bridge.cpp`, `build.sh` — the bridge and its build.
- `serve.py` — no-cache dev server. `web/presets.json` — built-in playlist.

three.js is loaded from a CDN via an import map (pinned version), so there is
no bundler and no `node_modules`.

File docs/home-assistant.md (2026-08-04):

# Home Assistant integration

The firmware speaks MQTT with Home Assistant discovery: point the cube at
your broker and it announces itself — no YAML needed for the entities.

## Setup

1. Have a broker. On Home Assistant OS that's the **Mosquitto broker**
   add-on plus the **MQTT** integration (discovery is on by default).
2. On the cube, open `http://cube.local/wifi` → **Home Assistant (MQTT)**:
   tick *Enable MQTT*, enter the broker host (e.g. `homeassistant.local` or
   its IP), port `1883`, and the MQTT username/password if your broker wants
   one. Save & reboot.
3. A **Cube Light** device appears in HA with four entities:

| Entity | What it does |
| --- | --- |
| `light.cube` | On/off + brightness. "Off" blanks the LEDs (and drops the energy-saving relay on the 618). |
| `select.cube_light_pattern` | Switch the live pattern (full registry). |
| `select.cube_light_preset` | Load a saved preset. Re-announced whenever presets change; hidden until at least one preset exists. |
| `text.cube_light_text` | Sets the text-3d message. Sticks across pattern swaps until reboot; a preset with its own text wins. |
| `switch.cube_light_playlist` | Play/pause the preset cycle — synced with the console, so a manually started cycle shows here too. |
| `switch.cube_light_shuffle` | Shuffle mode (priority-weighted). |
| `button.cube_light_next_preset` / `..._previous_preset` | Skip within the cycle (starts it if stopped). |
| `select.cube_light_playlist_collection` | Which curated playlist the cycle plays; "All presets" = the default pool. |

(Entity ids may differ slightly if you rename things; check the device page.)

## Curated playlists & demo dwell

Playlists are named subsets of the preset store (console → Presets sidebar →
playlist picker; tick presets in or out). `""`/"All presets" keeps today's
behavior. The REST surface: `GET /api/playlists`, `POST /api/playlists/save?name=X`
(body = JSON array of preset names in play order), `POST /api/playlists/delete`,
and `POST /api/playlist?list=X&dwell=N` — `dwell` overrides every preset's
dwell time (5–8s makes a great filming/demo reel; `0` returns to per-preset
times). In curated lists nothing is excluded: priority 0 plays at weight 1.

State flows both ways: changes made on the cube's own console (pattern picks,
playlist advances, brightness) publish back to HA within a moment, plus a 30s
keepalive republish. An availability topic (`cube/avail`, with LWT) grays the
entities out if the cube drops off the network.

## Show the current song title

The cube's 10×10 font is uppercase-only, so upper-case the title. The
trailing spaces give words breathing room between loops.

```yaml
automation:
  - alias: Cube shows current song
    trigger:
      - platform: state
        entity_id: media_player.living_room   # your player
        attribute: media_title
    condition:
      - "{{ trigger.to_state.attributes.media_title is not none }}"
    action:
      - service: select.select_option
        target: { entity_id: select.cube_light_pattern }
        data: { option: text-3d }
      - service: text.set_value
        target: { entity_id: text.cube_light_text }
        data:
          value: "{{ trigger.to_state.attributes.media_title | upper }}  "
```

Tip: turn on the text pattern's **Audio throb** params (`throbDepth` ≈ 0.4)
so the title pulses with the music; `throbRelease` tames the twitchiness.

## Album art (image-3d pattern)

`image-3d` shows a 10×10 downscale of an uploaded image on all four vertical
faces, over a fading background glow in the image's average color — both
throb to the beat.

Upload is HTTP, not MQTT: `POST /api/image?w=<w>&h=<h>` with a base64 body of
raw RGB24 bytes (row-major, top row first; up to 64×64 — the cube
box-averages down to 10×10). Extra query params: `show=1` switches the cube
to image-3d, `persist=0` skips the flash write (use it for once-per-song
pushes; without it the last art also survives reboots).

Home Assistant's container ships `ffmpeg`, which handles the fetch + scale +
raw conversion in one go. `media_player` entity pictures are signed URLs, so
no auth header is needed:

```yaml
shell_command:
  cube_album_art: >-
    /bin/bash -c 'ffmpeg -y -i "http://localhost:8123{{ art }}"
    -vf scale=32:32 -f rawvideo -pix_fmt rgb24 - 2>/dev/null
    | base64 | curl -s -H "Content-Type: application/octet-stream"
    --data-binary @- "http://cube.local/api/image?w=32&h=32&persist=0&show=1"'

automation:
  - alias: Cube shows album art
    trigger:
      - platform: state
        entity_id: media_player.living_room
        attribute: entity_picture
    condition:
      - "{{ trigger.to_state.attributes.entity_picture is not none }}"
    action:
      - service: shell_command.cube_album_art
        data:
          art: "{{ trigger.to_state.attributes.entity_picture }}"
```

(`base64` line-wraps its output; that's fine — the endpoint strips
whitespace. The `Content-Type: application/octet-stream` header matters:
without it the body is parsed as form data and the base64 gets mangled.)

Two gotchas learned deploying this for real (2026-08-04):
- **shell_command with templates is NOT run through a shell** — HA renders the
  template then `shlex.split`s and `exec`s it, so pipes only work via the
  `/bin/bash -c '...'` wrapper shown above. Keep the whole pipeline inside the
  single quotes.
- **Adding a brand-new top-level key (like `shell_command:`) needs a full HA
  restart** — `reload_all` only reloads integrations that were present at
  startup.

For a manually-triggered version, pair the shell_command with a script and
put it on a dashboard:

```yaml
script:
  cube_show_tv_amp_art:
    alias: "Cube: Show TV Amp Art"
    icon: mdi:image-album
    sequence:
      - service: shell_command.cube_show_art
        data:
          art: >-
            {{ state_attr('media_player.tv_amp','entity_picture_local')
               or state_attr('media_player.tv_amp','entity_picture') }}
```

## No broker? REST works too

Everything the MQTT entities do is also plain HTTP on the cube:

```yaml
rest_command:
  cube_text:
    url: "http://cube.local/api/text"
    method: POST
    content_type: application/x-www-form-urlencoded
    payload: "v={{ value }}&show=1"
  cube_power:
    url: "http://cube.local/api/power"
    method: POST
    content_type: application/x-www-form-urlencoded
    payload: "on={{ on }}"
```

Other useful endpoints: `POST /api/pattern` (`id=`), `POST /api/presets/load`
(`name=`), `POST /api/brightness` (`v=0..1`).

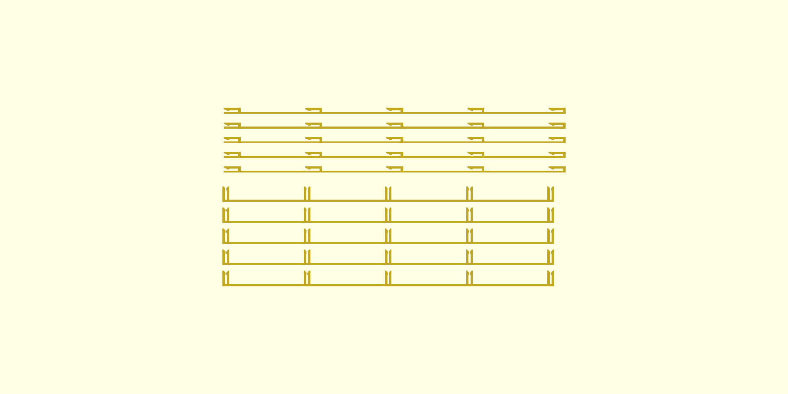
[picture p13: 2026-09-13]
hardware/clips/renders/struts-top.png

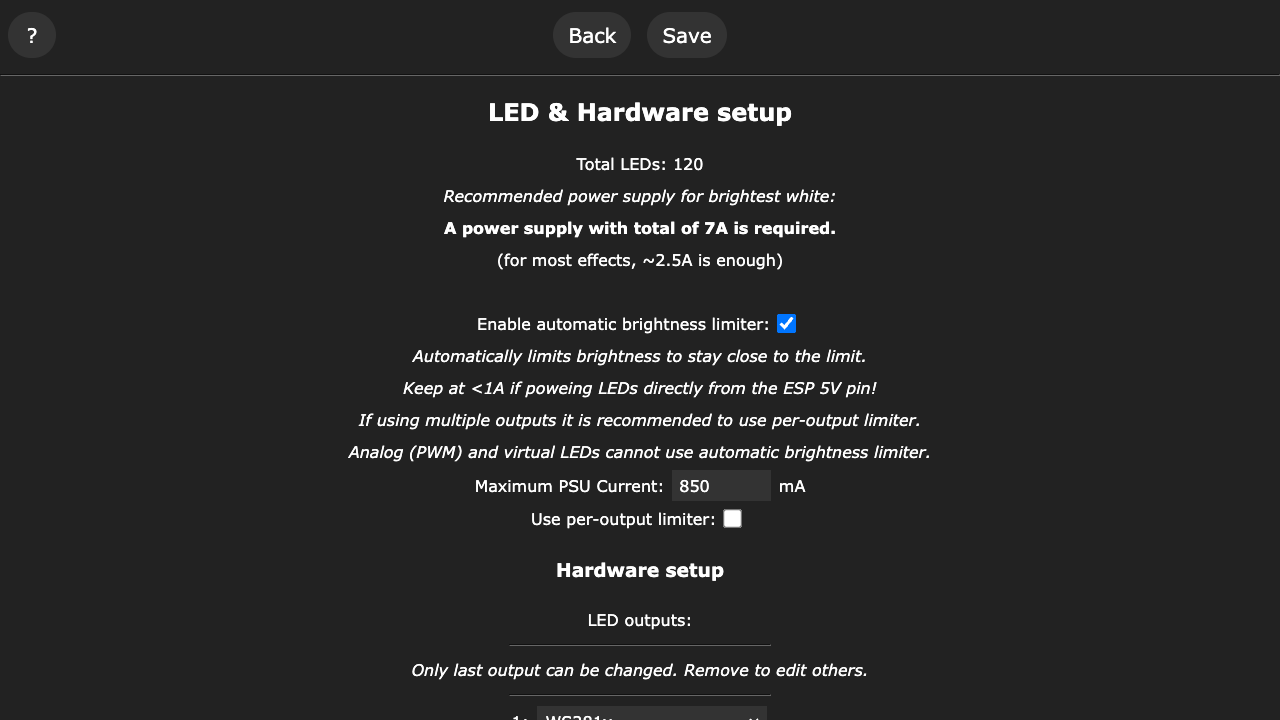
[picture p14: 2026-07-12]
docs/wled-backup/settings-leds.png

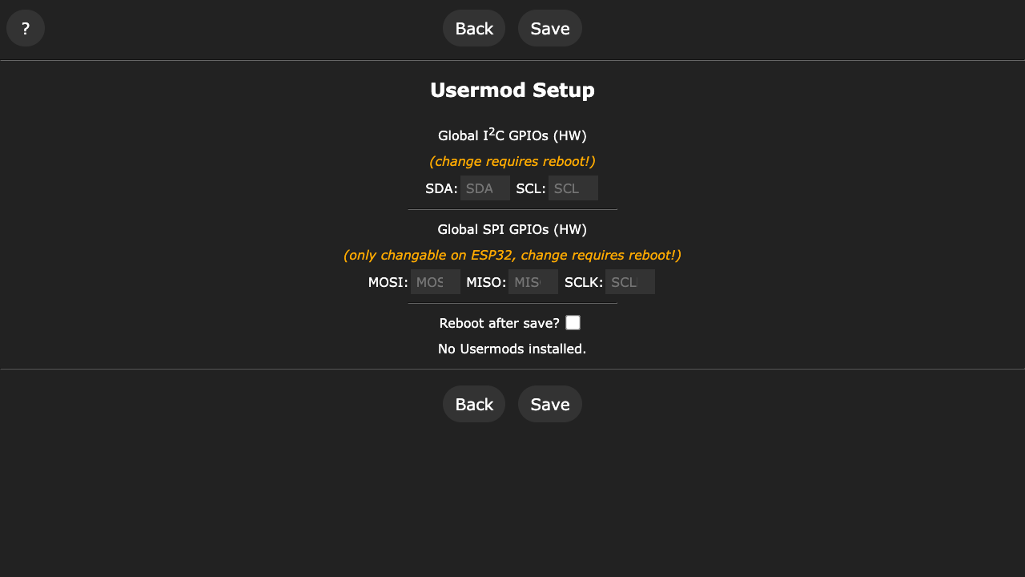
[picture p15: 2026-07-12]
docs/wled-backup/settings-um.png

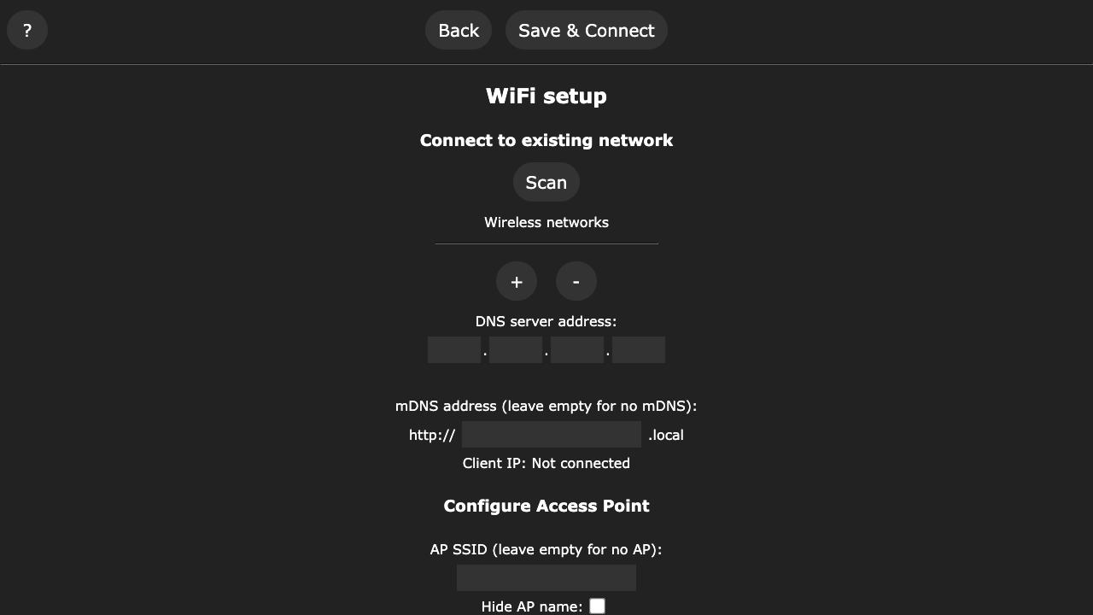
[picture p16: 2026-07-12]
docs/wled-backup/settings-wifi.png

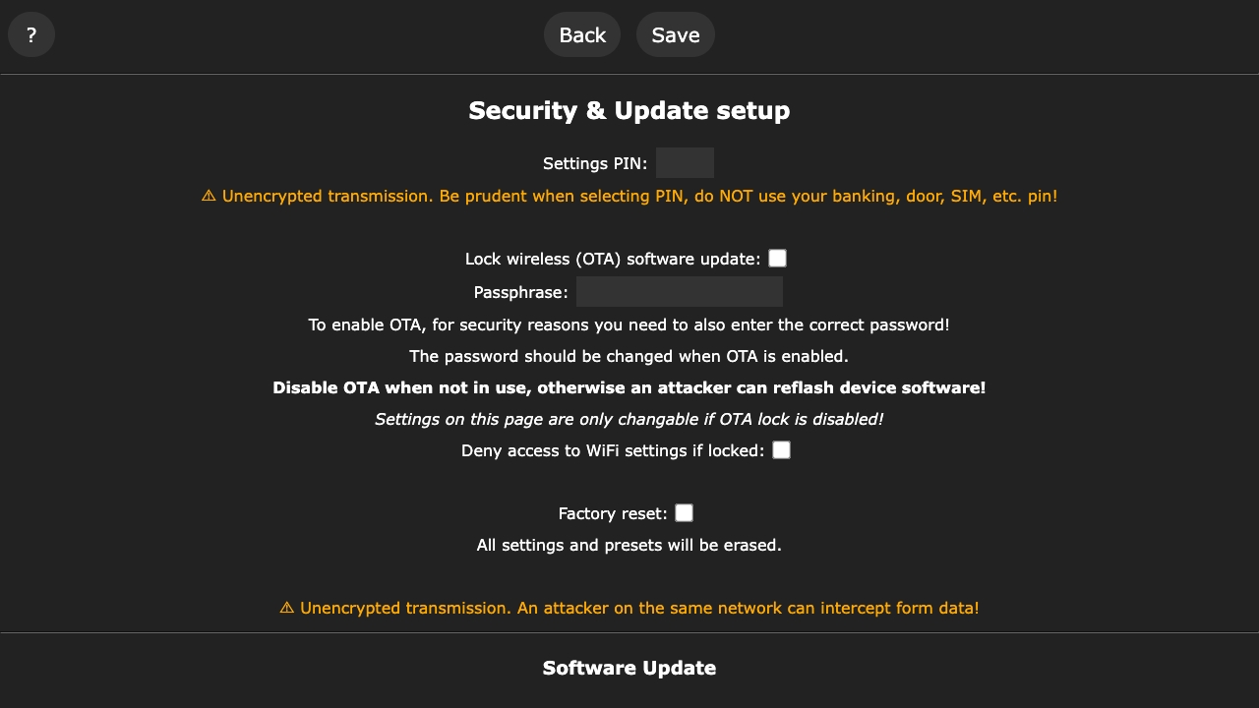
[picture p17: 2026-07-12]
docs/wled-backup/settings-sec.png

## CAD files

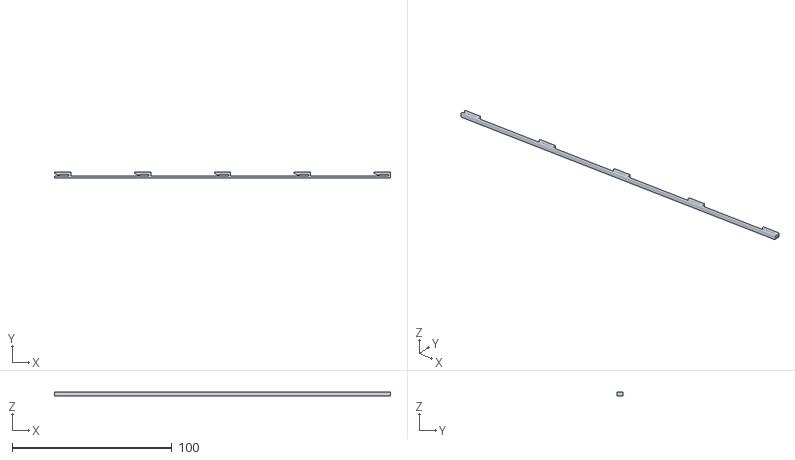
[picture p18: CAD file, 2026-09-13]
hardware/clips/strut-c24.stl
210.3 x 3.70 x 2.40

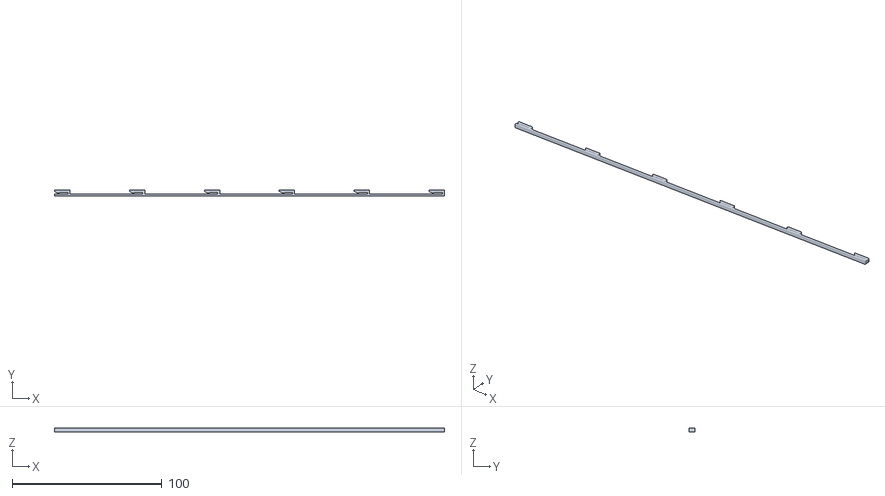
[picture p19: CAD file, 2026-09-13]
hardware/clips/strut6-c24.stl
260.3 x 3.70 x 2.40

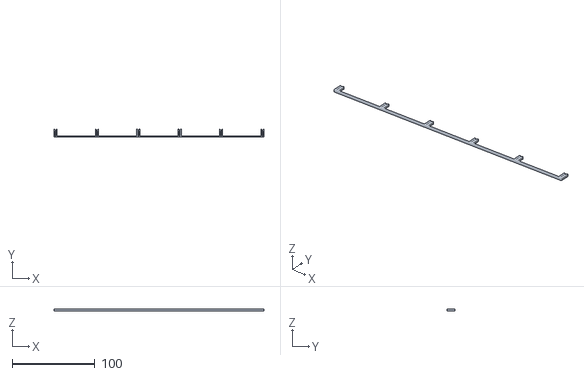
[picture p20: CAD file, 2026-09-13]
hardware/clips/strut6-u24.stl
253.9 x 9.50 x 2.40

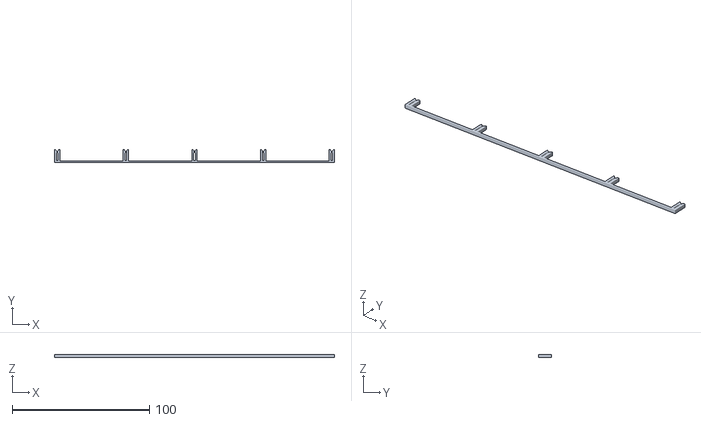
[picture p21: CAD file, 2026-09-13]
hardware/clips/strut-u24.stl
203.9 x 9.50 x 2.40

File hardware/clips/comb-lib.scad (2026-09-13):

// Shared clip/comb geometry for the light-cube struts.
// Consumers `include <comb-lib.scad>` and call the comb modules with a GAP LIST
// (n_clips - 1 entries), so uniform 50 mm grids and the alternating end-wrap
// spacing use the same code.
//
// Fixed dimensions here are the ones locked by the v2/v3 fit tests
// (pocket 1.2 on this bead-light wire); heights and mouths stay per-piece args.

$fn = 40;

// ---------- locked by fit tests ----------
// v6 (2026-08-21): pocket tightened 1.2 -> 1.1 after two weeks of real use at
// 2.4 mm / PETG — held fine but could hold better (v2 sweep already rated 1.1
// "tighter, better grip"). Override from the CLI: -D slot=1.2 for the old fit.
slot     = 1.1;    // pocket (v5 was 1.2)
bar_w    = 1.2;    // bar width in the printed plane

// ---------- clip internals ----------
depth    = 5.5;    // clear pocket length (ribbon ~4.8 wide edgewise)
wall     = 1.4;    // clip wall / finger thickness
back     = 1.4;    // back wall
throat   = 1.4;    // narrow mouth section length
flare    = 1.0;    // u-funnel extra half-width
flare_h  = 1.2;    // u-funnel height
c_ramp   = 0.6;    // c-barb entry ramp
c_flare  = 1.2;    // c finger-tip lead-in length
c_flareup= 0.6;    // ...lift at the tip
c_L      = 0.2 + c_ramp + throat + depth + back;   // c station length along x

// clip position i from a gap list (cumulative sum)
function clip_pos(gaps, i) = i <= 0 ? 0 : clip_pos(gaps, i-1) + gaps[i-1];
function span(gaps) = clip_pos(gaps, len(gaps));

// ---------- 2D stations ----------
// U: slot opens +y, back edge on y=0. Funnel -> throat -> square shelf -> pocket.
module u2d(mouth_) {
    PL = slot/2;  ML = mouth_/2;  TL = ML + flare;  O = slot/2 + wall;
    y1 = back;  y2 = back + depth;  y3 = y2 + throat;  y4 = y3 + flare_h;
    polygon([
        [-O,0],[O,0],[O,y4],[TL,y4],[ML,y3],[ML,y2],[PL,y2],[PL,y1],
        [-PL,y1],[-PL,y2],[-ML,y2],[-ML,y3],[-TL,y4],[-O,y4]
    ]);
}

// C: opening faces -x; the bar (y 0..bw) is the lower jaw.
module c2d(mouth_, bw = bar_w) {
    ys = bw + slot;         // finger underside
    yt = ys + wall;         // finger top
    ym = bw + mouth_;       // barb bottom = mouth gap over the bar
    polygon([[-c_flare, yt], [-c_flare, ys + c_flareup], [0, ys],
             [c_L, ys], [c_L, yt]]);                       // finger, lifted tip
    polygon([[0.2, ys + 0.2], [0.2 + c_ramp, ym],          // barb: ramp in,
             [0.2 + c_ramp + throat, ym],                  //  square face back
             [0.2 + c_ramp + throat, ys + 0.2]]);
    translate([c_L - back, 0]) square([back, yt]);         // back wall
}

// ---------- combs (bar integral, no tags) ----------
// bw = bar width in the printed plane. Narrow bars (<= back wall) sit inside the
// clips' back walls as before; wider bars extend BACKWARD (-y) from the pocket
// floor line so they never bury the slot openings.
// ang rotates each clip station relative to the bar (0 = perpendicular slots).
// For diagonal struts the wires stay grid-aligned, so ang = 45: clips sit at
// 45/135 to the bar. Rotated stations are trimmed flush with the bar's bottom
// edge (the pocket stays clear of the trim; the bar backs the wall there).
// A flat part flipped upside-down mirrors ang -> one export serves both
// diagonal directions.
// No `alt` here (unlike c_comb): a U pocket sits ~4 mm to the SIDE of the bar,
// so flipping every second clip to the other side (u_n_u_n_u) would put the
// wires on an 8 mm zigzag instead of one straight grid line. Only the C, whose
// wire lies on the bar's own line, can alternate.
module u_comb(h_, mouth_, gaps, bw = bar_w, ang = 0) {
    O  = slot/2 + wall;
    y0 = bw <= back ? 0 : back - bw;
    linear_extrude(h_) {
        for (i = [0 : len(gaps)]) translate([clip_pos(gaps, i), 0]) {
            intersection() {
                rotate(ang) u2d(mouth_);
                translate([-50, y0]) square([100, 100]);   // trim below bar bottom
            }
            // gusset: an angled station leaves an acute re-entrant notch where
            // its underside meets the bar top — a stress riser on a ~bar_w-wide
            // weld. Fill it with a triangular web: apex anchored inside the
            // clip's outer wall, base overlapping the bar.
            if (ang != 0) {
                a    = abs(ang);
                apex = [ (O - 0.7)*cos(a) - 2.5*sin(a),
                         (O - 0.7)*sin(a) + 2.5*cos(a) ];
                gx   = bw / tan(a) + 3;                     // base reach along bar
                mirror([ang < 0 ? 1 : 0, 0])
                    polygon([apex, [0, bw - 0.2], [gx, bw - 0.2]]);
            }
        }
        translate([-O, y0]) square([span(gaps) + 2*O, bw]);
    }
}

// alt = true mirrors every second station ALONG the bar (about its pocket
// centre, so the 50 mm pitch is unchanged): openings face -x, +x, -x, ...
// The bar is still the lower jaw of every clip, and every wire still sits on
// the bar's line (y = bw + slot/2) -- which is why C can alternate and U can't. A plain C-comb installs by
// sliding ~8 mm along its own axis and comes off the same way; an alternating
// one can't slide off at all, but each wire is pressed over its barb
// individually (odd wires one way, even wires the other).
c_pc = ((0.2 + c_ramp + throat) + (c_L - back)) / 2;       // pocket centre in x
module c_comb(h_, mouth_, gaps, bw = bar_w, alt = false) {
    n  = len(gaps) + 1;
    // station extents: normal [-c_flare, c_L]; mirrored [2*c_pc - c_L, 2*c_pc + c_flare]
    x_lo = -c_flare;
    x_hi = span(gaps) + ((alt && (n-1) % 2 == 1) ? 2*c_pc + c_flare : c_L);
    linear_extrude(h_) {
        for (i = [0 : len(gaps)]) translate([clip_pos(gaps, i), 0]) {
            flip = alt && (i % 2 == 1);
            translate([flip ? 2*c_pc : 0, 0]) mirror([flip ? 1 : 0, 0]) c2d(mouth_, bw);
        }
        translate([x_lo, 0]) square([x_hi - x_lo, bw]);
    }
}

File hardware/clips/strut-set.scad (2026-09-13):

// Light-cube strut set — v4: production-candidate combs, thickness sweep
//
// Findings driving this version:
//   - pocket 1.2 confirmed perfect (v3 U1.2 comb)
//   - happy accident: combs from the spaghetti-failed plates — only a couple of
//     layers tall — turned out to work WELL for this use. So part thickness (Z)
//     becomes the swept variable, and thin is a feature: near-invisible struts.
//   - thinner parts flex more, so the mouth TIGHTENS as thickness drops to keep
//     retention (paired lists below).
//   - no more label tags — pieces are told apart by their thickness.
//
// 5 U-combs + 5 C-combs, 5 clips each at 50 mm pitch.
// Intended use: thicker struts on the cube's outer layers, thinner inside.
// Heights are exact multiples of 0.2 -> slice at 0.2 mm layers.
//
// Per-object export (so any comb can be skipped mid-print):
//   for p in u06 u10 u16 u24 u32 c06 c10 c16 c24 c32:
//     openscad -o strut-$p.stl -D 'part="$p"' strut-set.scad
//   6-clip:           add -D n_clips=6          (254 / 260 mm -> place diagonally)
//   alternating:      add -D alt=true           (C only: openings flip clip to clip)
//   v5 pocket (1.2):  add -D slot=1.2           (v6 default is 1.1)
// v6 exports live in v6/ (see README) so the printed v5 files stay untouched.
//
// Clip geometry lives in comb-lib.scad (shared with end-strut.scad).

include <comb-lib.scad>

part = "all";   // "all" or one of u06|u10|u16|u24|u32|c06|c10|c16|c24|c32
alt  = false;   // true: C-combs alternate opening direction along the bar (see comb-lib).
                // Ignored for U-combs -- their pockets sit beside the bar, so flipping
                // would zigzag the wires off the grid line.
                // pocket width: comb-lib's `slot` (v6 = 1.1); -D slot=1.2 for the v5 fit

bar_width = 1.2;   // standard 1.2; 3.6 is the stiffer option:
                   //   openscad -o strut-w36-<part>.stl -D bar_width=3.6 -D 'part="..."' strut-set.scad

// ---------- the sweep: thickness -> mouth (paired) ----------
// v5 mouths (field-tested 2026-07-08): thin struts are so flexible the mouth can
// pinch far tighter — 0.45 up through 1.6 mm; 0.75 at 3.2+; 2.4 interpolated.
heights = [0.6, 1.0, 1.6, 2.4, 3.2];      // part height (Z); thin = inner layers
mouths  = [0.45, 0.45, 0.45, 0.60, 0.75]; // snap gap, tighter when thinner
ids_u   = ["u06", "u10", "u16", "u24", "u32"];
ids_c   = ["c06", "c10", "c16", "c24", "c32"];

n_clips = 5;
pitch   = 50;
grid_gaps = [for (i = [1 : n_clips-1]) pitch];

module show(p) { if (part == "all" || part == p) children(); }

for (i = [0 : len(heights)-1]) {
    show(ids_u[i]) translate([0, 13*i,     0]) u_comb(heights[i], mouths[i], grid_gaps, bar_width);
    show(ids_c[i]) translate([0, 70 + 9*i, 0]) c_comb(heights[i], mouths[i], grid_gaps, bar_width, alt = alt);
}

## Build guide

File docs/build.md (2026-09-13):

# Building the cube

The physical build, as far as this repo knows it. Sections marked **TODO** need
the builder's photos and part links; the electrical facts below come from the
firmware and the boards' recorded configs.

## Bill of materials

| Part | Qty | Notes |
| --- | --- | --- |
| WS2811 12 V seed pixels, 50/string | 20 strings (1000 px) | Tiny "seed"/"fairy" pixels on thin wire, not 12 mm bullets. Search *WS2811 12V seed pixel string*. **TODO: link the exact listing used.** |
| Gledopto GL-C-618WL | 1 | Controller with mic, two outputs, relay, USB-C. [Product page](https://gledopto.com/h-pd-64.html). |
| 12 V PSU, 10 A+ | 1 | Firmware limiter defaults to 10 A. At the playa this ran from a 12 V battery bank. **TODO: which.** |
| Frame clips | ~40 combs | 3D-printed, translucent PETG. STLs and OpenSCAD source in [`hardware/clips/`](../hardware/clips/). |
| Wire, connectors | | 3-pin JST-SM pigtails are the norm on pixel strings. Inject power at the start of each 500-pixel chain at least. |

## Frame

The strings *are* the structure. Each vertical string of 100 pixels runs top
to bottom, U-turns, and comes back up the next column (a long snake), and the
columns are held 50 mm apart by flat 3D-printed combs with a snap clip every
50 mm. Clip a comb across a row of strings and it locks their spacing; do it in
both directions on every layer and the cube holds itself square with almost
nothing visible once it's lit.

- What didn't work: version one was two acrylic sheets, top and bottom, with
  holes drilled for the strings, hoping the bottom sheet's weight would keep
  everything taut. Getting the wires tight in between was fiddly and it looked
  sloppy.
- What did: the printed clips. Translucent PETG keeps the shape without
  obscuring the lights, and the scaffold reads as part of the design.
- Print instructions, U-vs-C clip notes, and the parametric source are in
  [`hardware/clips/README.md`](../hardware/clips/README.md).

## Wiring

- **Two chains of 500.** Output 1 drives pixels 0..499, output 2 drives
  500..999 (`CUBE_LED_SPLIT=500`). Running both halves in the same direction
  from their own start keeps the data path short.
- **Any physical order works.** Strings can run up/down alternately
  (serpentine, which is how this cube is wired: the first pixel is at the
  origin, the second is one step up, the tenth starts the next column, the
  two-hundredth the next slab), start from any corner, and the axes can be
  in any order. The
  calibration wizard at `/calibrate` figures out the mapping: it lights one
  pixel at a time, you tell it where that pixel is, and after a handful of
  samples the solver has narrowed 192 candidate layouts to one.
- **Color order** is set live from `/leds` (GRB is the default). Same for
  which output is which.
- **Dead pixels.** Cut them out and record how many were snipped from the
  start of each chain on `/leds`; the firmware shifts the data so the rest of
  the geometry stays put.

## Power

- WS2811 seed pixels draw roughly 15 mA at full white (`CUBE_PER_LED_MA`), so
  1000 of them would want ~15 A. The firmware scales brightness to keep the
  frame under `CUBE_SUPPLY_MA` (10 A default, adjustable on `/admin`); the
  sparse patterns this cube favors rarely approach it.
- The 618 has a relay on GPIO18 that cuts LED power when the cube is "off"
  from the console or Home Assistant. It must be driven high for the LEDs to
  light, which the firmware does at boot.
- The controller takes the same 12 V and regulates its own 5 V.

## Controller notes

- **GL-C-618WL**: PDM mic on GPIO32 (data) / GPIO15 (clock), button on 17,
  relay on 18, LED outputs on 16 and 12. Stock WLED config backup in
  `docs/wled-backup/`.
- **GL-C-310WL**: no USB (OTA only), I2S mic (SD 26 / WS 5 / SCK 21), output
  on 16 (a second on 2), spare pads on 12 and 33. The project's backup cube.
  Stock config in `docs/wled-backup-309/` (recorded before the model was
  pinned down; the mic is not configured in it).
- **GL-C-309WL**: the same board without the mic. A PDM mic can be added on
  the spare pads; see the note in `platformio.ini`.
- **Bare ESP32 + INMP441**: see `[env:esp32dev-inmp441]`. You'll want a
  74HCT-type level shifter on the data lines and a 12 V→5 V buck for the
  board.

## Photos

**TODO.** Frame, string routing, controller mount, the whole thing lit.

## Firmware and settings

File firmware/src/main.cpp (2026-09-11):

// ESP32 firmware entry point (Gledopto GL-C-618WL target).
//
// Status: skeleton, written ahead of hardware arrival — compiles under
// PlatformIO but is UNTESTED on a real board.
//
// BEFORE FIRST FLASH: open the stock WLED UI and record every pin mapping
// its settings pages show (LED GPIO, color order, button pin, mic pins,
// relay pin). Then set the CUBE_* build flags in platformio.ini to match.
//
// What it does:
//  - Settings persist in NVS (Preferences): WiFi credentials, AP/OTA
//    password, pattern, brightness, color order, power budget. Build flags
//    are only the first-boot defaults.
//  - Joins the configured WiFi; falls back to a WPA2 AP ("cube-light") if
//    no credentials or the join times out.
//  - Serves a phone-friendly control page at http://cube.local/ (pattern,
//    brightness, power budget, color order) and /wifi for network setup.
//  - Runs the shared pattern core at CUBE_FPS, applies brightness + a
//    WLED-style current limiter, pushes frames via NeoPixelBus (RMT).
//  - Listens for WLED DNRGB packets on UDP 21324; live packets override the
//    local pattern until their timeout lapses (same semantics as WLED), so
//    the Node dev server keeps working unchanged.
//  - Function button short-press cycles patterns (works with no network).
//  - ArduinoOTA (password-protected) for wireless reflashing — DISARMED until
//    the owner opens a 15-minute window from /admin (see armOta()).
//
// Not yet here: mic capture + FFT -> BeatDetector, per-pattern params over
// the API, /snake controller page, full React-app WS contract.

#include <Arduino.h>
#include <ArduinoOTA.h>
#include <ESPmDNS.h>
#include <LittleFS.h>
#include <NeoPixelBus.h>
#include <Preferences.h>
#include <WebServer.h>
#include <WiFi.h>
#include <WiFiUdp.h>
#include <esp_random.h>
#include <mbedtls/base64.h>

#include "audio_capture.h"
#include "cube_image.h"
#include "cube_calibration.h"
#include "cube_mod.h"
#include "cube_pacman.h"
#include "cube_palettes.h"
#include "cube_param_specs.h"
#include "cube_pattern.h"
#include "cube_presets.h"
#include "cube_snake.h"
#include "cube_power.h"
#include "ha_mqtt.h"
#include "web_ui.h"

#define CUBE_VERSION "0.5.0"

#ifndef CUBE_LED_PIN
#define CUBE_LED_PIN 16
#endif
// Second output: the cube's 1000-LED chain is cut at the wire midpoint and
// fed as two 500-LED runs (halves transmit time -> 60fps ceiling, halves
// data-error propagation, and pairs with power injection at both feed
// points). The second half must be fed at its ORIGINAL START (where LED
// CUBE_LED_SPLIT used to take data), keeping wire direction unchanged, so
// the geometry mapping stays valid. Set CUBE_LED_PIN2=-1 for one unbroken
// 1000-LED chain on CUBE_LED_PIN.
#ifndef CUBE_LED_PIN2
#define CUBE_LED_PIN2 12
#endif
#ifndef CUBE_LED_SPLIT
#define CUBE_LED_SPLIT 500  // LEDs on output 1; the rest go to output 2
#endif
#ifndef CUBE_FPS
#define CUBE_FPS 30
#endif
#ifndef CUBE_COLOR_ORDER
#define CUBE_COLOR_ORDER "RGB"
#endif
#ifndef CUBE_SUPPLY_MA
#define CUBE_SUPPLY_MA 10000
#endif
#ifndef CUBE_PER_LED_MA
#define CUBE_PER_LED_MA 15
#endif
#ifndef CUBE_IDLE_MA_PER_LED
#define CUBE_IDLE_MA_PER_LED 0.5f
#endif
#ifndef CUBE_BUTTON_PIN
#define CUBE_BUTTON_PIN 17  // 618WL function button (from stock WLED cfg); -1 disables
#endif
#ifndef CUBE_RELAY_PIN
// The 618WL has an energy-saving relay that cuts LED V+ when "off". Stock
// WLED drives it on GPIO18 (active high). If we don't raise it, the string
// stays dark no matter what we clock out. -1 disables.
#define CUBE_RELAY_PIN 18
#endif
#ifndef CUBE_AP_PASS
#define CUBE_AP_PASS "cubelight"  // default AP+OTA password; change via /wifi
#endif
#ifndef CUBE_MDNS_NAME
#define CUBE_MDNS_NAME "cube"  // mDNS host — give a second cube its own name
#endif
// Optional baked-in first-boot WiFi, for OTA-only boards that must come up on
// the LAN right after their first flash (no USB rescue). Credentials stay out
// of git: pass at build time via
//   PLATFORMIO_BUILD_FLAGS='-DCUBE_WIFI_SSID=\"...\" -DCUBE_WIFI_PASS=\"...\"'
// NVS-saved credentials always win; these are only the empty-NVS defaults.
#ifndef CUBE_WIFI_SSID
#define CUBE_WIFI_SSID ""
#endif
#ifndef CUBE_WIFI_PASS
#define CUBE_WIFI_PASS ""
#endif

using namespace cube;

// ---- persisted settings -----------------------------------------------------

struct Settings {
  String wifiSsid;
  String wifiPass;
  String apPass;      // WPA2 AP password, doubles as the OTA password
  String uiPass;      // optional HTTP auth for the settings console ("" = off)
  String patternId;
  String colorOrder;  // "RGB", "GRB", ...
  float brightness;   // 0..1
  uint32_t supplyMA;  // 0 = limiter off
  Layout layout;      // wiring calibration
  String upAxis;      // "z+","z-","x+","x-","y+","y-"
  int ledPin;         // output 1 GPIO
  int ledPin2;        // output 2 GPIO; -1 = single unbroken chain
  int ledSplit;       // LEDs on output 1 when split
  int ledSkip1;       // LEDs snipped off the START of output 1's chain
  int ledTrim1;       // LEDs snipped off the END of output 1's chain
  int ledSkip2;       // same, output 2
  int ledTrim2;
  bool micLeft;       // PDM channel format
  float micSquelch;   // raw RMS below this = silence
  bool micEnabled;    // master toggle: false = patterns see silence
  bool powerOn;       // HA light switch: false = dark (relay dropped if fitted)
  bool apGuests;      // true = hotspot clients are guests; false = the WPA2
                      // password is the only gate and AP clients are owners
  bool mqttEnabled;   // Home Assistant MQTT integration
  String mqttHost;
  uint16_t mqttPort;
  String mqttUser;
  String mqttPass;
};

Preferences prefs;
Settings settings;

void loadSettings() {
  prefs.begin("cube", true);
  settings.wifiSsid = prefs.getString("ssid", CUBE_WIFI_SSID);
  settings.wifiPass = prefs.getString("pass", CUBE_WIFI_PASS);
  settings.apPass = prefs.getString("appass", CUBE_AP_PASS);
  settings.uiPass = prefs.getString("uipass", "");
  settings.patternId = prefs.getString("pattern", kDefaultPatternId);
  settings.colorOrder = prefs.getString("order", CUBE_COLOR_ORDER);
  settings.brightness = prefs.getFloat("bright", 1.0f);
  settings.supplyMA = prefs.getUInt("supply", CUBE_SUPPLY_MA);
  settings.layout.flipX = prefs.getBool("flipx", false);
  settings.layout.flipY = prefs.getBool("flipy", false);
  settings.layout.flipZ = prefs.getBool("flipz", false);
  settings.layout.ledOffset = prefs.getInt("ledoff", 0);
  settings.upAxis = prefs.getString("up", "z+");
  // Default is a single unbroken 1000-LED chain on output 1; set pin2/split
  // from the console once the chain is physically cut in half.
  settings.ledPin = prefs.getInt("ledpin", CUBE_LED_PIN);
  settings.ledPin2 = prefs.getInt("ledpin2", -1);
  settings.ledSplit = prefs.getInt("ledsplit", CUBE_LED_SPLIT);
  settings.ledSkip1 = prefs.getInt("skip1", 0);
  settings.ledTrim1 = prefs.getInt("trim1", 0);
  settings.ledSkip2 = prefs.getInt("skip2", 0);
  settings.ledTrim2 = prefs.getInt("trim2", 0);
  settings.micLeft = prefs.getBool("micleft", false);
  settings.micSquelch = prefs.getFloat("micsq", 60.0f);
  settings.micEnabled = prefs.getBool("micen", true);
  settings.powerOn = prefs.getBool("power", true);
  settings.apGuests = prefs.getBool("apguests", true);
  settings.mqttEnabled = prefs.getBool("mqen", false);
  settings.mqttHost = prefs.getString("mqhost", "");
  settings.mqttPort = (uint16_t)prefs.getUInt("mqport", 1883);
  settings.mqttUser = prefs.getString("mquser", "");
  settings.mqttPass = prefs.getString("mqpass", "");
  prefs.end();
}

void saveHardware() {
  prefs.begin("cube", false);
  prefs.putInt("ledpin", settings.ledPin);
  prefs.putInt("ledpin2", settings.ledPin2);
  prefs.putInt("ledsplit", settings.ledSplit);
  prefs.putInt("skip1", settings.ledSkip1);
  prefs.putInt("trim1", settings.ledTrim1);
  prefs.putInt("skip2", settings.ledSkip2);
  prefs.putInt("trim2", settings.ledTrim2);
  prefs.putBool("micleft", settings.micLeft);
  prefs.putFloat("micsq", settings.micSquelch);
  prefs.end();
}

void saveLayoutAndUp() {
  prefs.begin("cube", false);
  prefs.putBool("flipx", settings.layout.flipX);
  prefs.putBool("flipy", settings.layout.flipY);
  prefs.putBool("flipz", settings.layout.flipZ);
  prefs.putInt("ledoff", settings.layout.ledOffset);
  prefs.putString("up", settings.upAxis);
  prefs.end();
}

void saveSetting(const char* key, const String& v) {
  prefs.begin("cube", false);
  prefs.putString(key, v);
  prefs.end();
}
void saveSetting(const char* key, float v) {
  prefs.begin("cube", false);
  prefs.putFloat(key, v);
  prefs.end();
}
void saveSetting(const char* key, uint32_t v) {
  prefs.begin("cube", false);
  prefs.putUInt(key, v);
  prefs.end();
}
void saveSetting(const char* key, bool v) {
  // NVS skips the write when the stored value already matches, so calling
  // this redundantly (e.g. per button press) costs a read, not flash wear.
  prefs.begin("cube", false);
  prefs.putBool(key, v);
  prefs.end();
}

// ---- LED output ---------------------------------------------------------------

// Feature fixed at RGB; configured color order is a runtime permutation
// applied while copying into the strip. Pins and the single/dual split are
// runtime settings: strips live on the heap and are torn down + rebuilt by
// initStrips() when hardware config changes (NeoPixelBus releases its RMT
// channel on destruction). Two buses transmit concurrently when split.
using Strip1T = NeoPixelBus<NeoRgbFeature, NeoEsp32Rmt0Ws2811Method>;
using Strip2T = NeoPixelBus<NeoRgbFeature, NeoEsp32Rmt1Ws2811Method>;
Strip1T* strip1 = nullptr;
Strip2T* strip2 = nullptr;
int stripSplit = NUM_LEDS;  // LEDs on output 1

void initStrips() {
  delete strip1;
  strip1 = nullptr;
  delete strip2;
  strip2 = nullptr;
  const bool dual = settings.ledPin2 >= 0 && settings.ledSplit > 0 &&
                    settings.ledSplit < NUM_LEDS;
  stripSplit = dual ? settings.ledSplit : NUM_LEDS;
  strip1 = new Strip1T(stripSplit, settings.ledPin);
  strip1->Begin();
  strip1->Show();
  if (dual) {
    strip2 = new Strip2T(NUM_LEDS - stripSplit, settings.ledPin2);
    strip2->Begin();
    strip2->Show();
  }
  Serial.printf("[led] pin1=%d n=%d%s\n", settings.ledPin, stripSplit,
                dual ? (" pin2=" + String(settings.ledPin2) + " n=" +
                        String(NUM_LEDS - stripSplit)).c_str()
                     : " (single chain)");
}

// Debug-only snip simulation, per output (NOT persisted — a reboot always
// clears it): pretend an intact chain lost simSkip[] LEDs at its start /
// simTrim[] at its end, so the ledSkip/ledTrim compensation can be rehearsed
// before (or without) cutting real LEDs. Set via POST /api/ledsim.
int simSkip[2] = {0, 0};
int simTrim[2] = {0, 0};

uint8_t colorPerm[3] = {0, 1, 2};  // perm[wireSlot] = source channel (0=R 1=G 2=B)

void applyColorOrder(const String& order) {
  for (int i = 0; i < 3 && i < (int)order.length(); i++) {
    colorPerm[i] = order[i] == 'G' ? 1 : order[i] == 'B' ? 2 : 0;
  }
}

// Push the logical frame to the strips, compensating for physically removed
// LEDs (burnt-out pixels snipped off a chain). If an output lost `ledSkip`
// LEDs at its start, data now enters at what used to be wire position
// base+skip — so data slot p carries logical LED (base + skip + p), every
// surviving LED keeps its calibrated position, and the snipped spots simply
// go dark. LEDs trimmed off the END need no shift; `ledTrim` just marks that
// tail absent. The simSkip/simTrim counters do the inverse on intact
// hardware: wire slot s displays what data slot (s - simSkip) would land
// there on a snipped chain, with the "missing" slots forced dark — so
// sim N + skip N should look identical to an untouched cube minus N LEDs.
void show(const uint8_t* rgb) {
  if (!strip1) return;
  const float limit = currentLimitScale(rgb, NUM_LEDS, CUBE_PER_LED_MA,
                                        CUBE_IDLE_MA_PER_LED, settings.supplyMA);
  const float k = limit * settings.brightness;
  const int base[2] = {0, stripSplit};
  const int len[2] = {stripSplit, NUM_LEDS - stripSplit};
  const int skip[2] = {settings.ledSkip1, settings.ledSkip2};
  const int trim[2] = {settings.ledTrim1, settings.ledTrim2};
  for (int o = 0; o < 2; o++) {
    if (o == 1 && !strip2) break;
    for (int s = 0; s < len[o]; s++) {
      RgbColor c(0, 0, 0);
      if (s >= simSkip[o] && s < len[o] - simTrim[o]) {
        const int li = base[o] + skip[o] + (s - simSkip[o]);
        if (li < base[o] + len[o] - trim[o]) {
          const uint8_t* px = rgb + li * 3;
          c = RgbColor((uint8_t)(px[colorPerm[0]] * k),
                       (uint8_t)(px[colorPerm[1]] * k),
                       (uint8_t)(px[colorPerm[2]] * k));
        }
      }
      if (o == 0) strip1->SetPixelColor(s, c);
      else strip2->SetPixelColor(s, c);
    }
  }
  strip1->Show();
  if (strip2) strip2->Show();
}

// ---- pattern engine -----------------------------------------------------------

Geometry geo;

void applyGeometry() {
  geo.rebuild(settings.layout, upAxisFromString(settings.upAxis.c_str()));
}

Params params;
ModStore mods;  // per-param automatic modulation (cube-la3), current pattern only
AudioFrame audio;  // refreshed each frame from the mic capture task
uint8_t frame[NUM_LEDS * 3];
const Pattern* activePattern = nullptr;
int activePatternIdx = 0;
PatternCtx ctx{frame, &geo, 0, 0, &audio, &params};
uint32_t patternStartMs = 0;
float lastT = 0;

// ---- Home Assistant bridge state ----
HaMqtt haMqtt;
// Last text pushed via MQTT/`/api/text` (song titles). Re-applied whenever
// text-3d becomes active, since a pattern switch reloads NVS params over it.
// A preset that includes its own text still wins (params apply after init).
String g_haText;
String g_currentPreset;  // last loaded preset name; "" after a manual change

// Effective (override-or-default) value of one spec, as a String.
String effectiveParam(const ParamSpec& sp) {
  switch (sp.type) {
    case 1: return params.boolean(sp.key, sp.defNum != 0) ? "1" : "0";
    case 2:
    case 3:
    case 4: return String(params.str(sp.key, sp.defStr));
    default: return String(params.num(sp.key, sp.defNum), 3);
  }
}

void applyParamFromString(const ParamSpec& sp, const String& v) {
  switch (sp.type) {
    case 1: params.setBool(sp.key, v == "1" || v == "true"); break;
    case 2:
    case 3:
    case 4: params.setStr(sp.key, v.c_str()); break;
    default: params.setNum(sp.key, v.toFloat()); break;
  }
}

// Saved param overrides live in NVS as "key=value\n" blobs per pattern.
String paramsKeyFor(int idx) {
  // NVS keys cap at 15 chars; ids are unique within their first 13.
  return "pp" + String(kPatterns[idx]->id).substring(0, 13);
}

void loadPatternParams(int idx) {
  prefs.begin("cube", true);
  const String blob = prefs.getString(paramsKeyFor(idx).c_str(), "");
  prefs.end();
  if (blob.length() == 0) return;
  const PatternSpecs* ps = specsFor(kPatterns[idx]->id);
  if (!ps) return;
  int pos = 0;
  while (pos < (int)blob.length()) {
    int nl = blob.indexOf('\n', pos);
    if (nl < 0) nl = blob.length();
    const String line = blob.substring(pos, nl);
    const int eq = line.indexOf('=');
    if (eq > 0) {
      const String key = line.substring(0, eq);
      for (int i = 0; i < ps->count; i++) {
        if (key == ps->specs[i].key) {
          applyParamFromString(ps->specs[i], line.substring(eq + 1));
          break;
        }
      }
    }
    pos = nl + 1;
  }
}

void savePatternParams(int idx) {
  const PatternSpecs* ps = specsFor(kPatterns[idx]->id);
  if (!ps) return;
  String blob;
  for (int i = 0; i < ps->count; i++) {
    blob += ps->specs[i].key;
    blob += '=';
    blob += effectiveParam(ps->specs[i]);
    blob += '\n';
  }
  prefs.begin("cube", false);
  prefs.putString(paramsKeyFor(idx).c_str(), blob);
  prefs.end();
}

// Modulation configs live in NVS beside the param overrides, one blob per
// pattern, keyed "pm<id13>". Lines are "key=mode,min,max,rate,step".
String modKeyFor(int idx) {
  return "pm" + String(kPatterns[idx]->id).substring(0, 13);
}

void loadPatternMods(int idx) {
  mods.clear();
  prefs.begin("cube", true);
  const String blob = prefs.getString(modKeyFor(idx).c_str(), "");
  prefs.end();
  if (blob.length() == 0) return;
  const PatternSpecs* mps = specsFor(kPatterns[idx]->id);
  int pos = 0;
  while (pos < (int)blob.length()) {
    int nl = blob.indexOf('\n', pos);
    if (nl < 0) nl = blob.length();
    const String line = blob.substring(pos, nl);
    pos = nl + 1;
    const int eq = line.indexOf('=');
    if (eq <= 0) continue;
    const String key = line.substring(0, eq);
    const String v = line.substring(eq + 1);
    const int c1 = v.indexOf(',');
    const int c2 = c1 < 0 ? -1 : v.indexOf(',', c1 + 1);
    const int c3 = c2 < 0 ? -1 : v.indexOf(',', c2 + 1);
    const int c4 = c3 < 0 ? -1 : v.indexOf(',', c3 + 1);
    if (c4 < 0) continue;
    const uint8_t mode = ModStore::modeFromName(v.substring(0, c1).c_str());
    if (mode == ModStore::OFF) continue;
    float mn = v.substring(c1 + 1, c2).toFloat();
    float mx = v.substring(c2 + 1, c3).toFloat();
    const float rate = v.substring(c3 + 1, c4).toFloat();
    const float step = v.substring(c4 + 1).toFloat();
    // Don't trust the NVS blob: clamp bounds to the spec range (out-of-range
    // mod bounds can push patterns outside their safe input domain — and a
    // bad blob would otherwise re-arm the hazard on every boot).
    const ParamSpec* msp = nullptr;
    if (mps)
      for (int i = 0; i < mps->count; i++)
        if (key == mps->specs[i].key) { msp = &mps->specs[i]; break; }
    if (!msp || msp->type != 0) continue;
    mn = constrain(mn, msp->minV, msp->maxV);
    mx = constrain(mx, msp->minV, msp->maxV);
    mods.set(key.c_str(), mode, mn, mx, rate, step, params.num(key.c_str(), mn),
             msp->stepV, msp->minV);
  }
}

void savePatternMods(int idx) {
  String blob;
  for (int i = 0; i < mods.count(); i++) {
    const ModStore::Entry* e = mods.at(i);
    blob += e->key;
    blob += '=';
    blob += ModStore::modeName(e->mode);
    blob += ',' + String(e->minV, 4) + ',' + String(e->maxV, 4) + ',' +
            String(e->rate, 4) + ',' + String(e->step, 4) + '\n';
  }
  prefs.begin("cube", false);
  if (blob.length())
    prefs.putString(modKeyFor(idx).c_str(), blob);
  else
    prefs.remove(modKeyFor(idx).c_str());
  prefs.end();
}

// `persist=false` skips the NVS write — used by transient switches (playlist
// advances, the snake-cal wizard) so automatic cycling doesn't wear flash or
// change what the cube boots into.
void setPatternByIndex(int i, bool persist = true) {
  activePatternIdx = ((i % kPatternCount) + kPatternCount) % kPatternCount;
  activePattern = kPatterns[activePatternIdx];
  patternStartMs = millis();
  lastT = 0;
  ctx.t = 0;
  ctx.dt = 0;
  params.clear();
  loadPatternParams(activePatternIdx);
  loadPatternMods(activePatternIdx);
  if (activePattern->init) activePattern->init(ctx);
  settings.patternId = activePattern->id;
  if (!strcmp(activePattern->id, "text-3d") && g_haText.length())
    params.setStr("text", g_haText.c_str());
  g_currentPreset = "";
  haMqtt.markDirty();
  if (persist) saveSetting("pattern", settings.patternId);
  Serial.printf("[pattern] %s\n", activePattern->id);
}

void setPatternById(const String& id, bool persist = true) {
  for (int i = 0; i < kPatternCount; i++) {
    if (id == kPatterns[i]->id) {
      setPatternByIndex(i, persist);
      return;
    }
  }
}
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
void loop() {
  netTick();
  if (!servicesStarted) {
    // Nothing else runs until the network is up: rendering to the RMT
    // while the join handshake is in flight is part of the crash recipe.
    delay(2);
    return;
  }
  if (otaArmed) {
    ArduinoOTA.handle();
    if ((int32_t)(millis() - otaDisarmAtMs) > 0) disarmOta();  // window lapsed
  }
  server.handleClient();
  if (WiFi.status() == WL_CONNECTED) haMqtt.loop();
  handleRealtime();
  handleButton();
  playlistTick();
  // Snake-cal wizard watchdog: restore the prior pattern if the page was
  // abandoned (5 min), and abort the wizard if something else (the physical
  // button) switched the pattern out from under it.
  if (snakeCalIndex >= 0) {
    if (millis() - snakeCalStartMs > 5UL * 60UL * 1000UL) {
      snakeCalIndex = -1;
      setPatternById(snakeCalReturnPattern.length() ? snakeCalReturnPattern
                                                    : String("snake-3d"),
                     /*persist=*/false);
    } else if (settings.patternId != "snake-cal") {
      snakeCalIndex = -1;
    }
  }

  static uint32_t nextFrameMs = 0;
  const uint32_t now = millis();
  if (now < nextFrameMs) return;
  nextFrameMs = now + 1000 / CUBE_FPS;

  // "Off" (HA light switch): the frame was blanked (and the relay dropped)
  // by setCubePower; skip rendering — including live DNRGB — until on again.
  if (!settings.powerOn) return;

  if (now < liveUntilMs) {
    show(liveFrame);  // dev server (or any WLED sender) has the cube
    return;
  }

  if (settings.micEnabled) {
    audioCaptureRead(audio);
  } else {
    audio = AudioFrame{};  // reactivity off: patterns see silence
  }
  const float t = (now - patternStartMs) / 1000.0f;
  ctx.t = t;
  ctx.dt = t - lastT;
  lastT = t;
  mods.tick(params, now);  // drift any modulated params before render sees them
  activePattern->render(ctx);
  show(frame);
}

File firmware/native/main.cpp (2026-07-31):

// Native host harness: runs the exact firmware pattern core on the dev
// machine and streams frames as WLED DNRGB packets over UDP. Point it at a
// real WLED cube, or at the Node dev server running with VIRTUAL_WLED=1 to
// see the C++ engine's output in the browser's 3D preview.
//
// Usage:
//   ./cube-native [patternId] [key=value ...] [options]
// Options:
//   --host H       destination (default 127.0.0.1)
//   --port P       destination UDP port (default 21324)
//   --fps N        frame rate (default 30)
//   --seconds S    exit after S seconds (default: run forever)
//   --fake-audio   synthesize level/bands/beat so audio-reactive params move
// Params: bare key=value pairs; "true"/"false" parse as bool, numerics as
// float, anything else as string. E.g.:
//   ./cube-native wavy-sheet palette=arctic amp=2 --fake-audio

#include <arpa/inet.h>
#include <netinet/in.h>
#include <sys/socket.h>
#include <unistd.h>

#include <algorithm>
#include <cmath>
#include <cstdio>
#include <cstdlib>
#include <cstring>
#include <ctime>

#include "cube_pattern.h"

using namespace cube;

namespace {

constexpr int kMaxLedsPerPacket = 489;  // header 4B + 489*3B fits one MTU
constexpr uint8_t kDnrgbOpcode = 0x04;
constexpr uint8_t kTimeoutSecs = 2;

double nowSeconds() {
  timespec ts;
  clock_gettime(CLOCK_MONOTONIC, &ts);
  return ts.tv_sec + ts.tv_nsec / 1e9;
}

void sendFrame(int sock, const sockaddr_in& dst, const uint8_t* rgb) {
  uint8_t pkt[4 + kMaxLedsPerPacket * 3];
  for (int start = 0; start < NUM_LEDS; start += kMaxLedsPerPacket) {
    const int count = std::min(kMaxLedsPerPacket, NUM_LEDS - start);
    pkt[0] = kDnrgbOpcode;
    pkt[1] = kTimeoutSecs;
    pkt[2] = (uint8_t)(start >> 8);
    pkt[3] = (uint8_t)(start & 0xff);
    std::memcpy(pkt + 4, rgb + start * 3, count * 3);
    sendto(sock, pkt, 4 + count * 3, 0, (const sockaddr*)&dst, sizeof(dst));
  }
}

void fakeAudio(AudioFrame& audio, double t) {
  // A plausible synthetic groove: slow level swell, per-band wobble, and a
  // 120 BPM beat envelope with exponential decay.
  audio.level = 0.35f + 0.3f * (float)std::sin(t * 0.7);
  for (int i = 0; i < AUDIO_BANDS; i++) {
    audio.bands[i] =
        0.5f + 0.5f * (float)std::sin(t * (1.1 + i * 0.37) + i * 1.7);
  }
  const double beatPeriod = 0.5;  // 120 BPM
  const double sinceBeat = std::fmod(t, beatPeriod);
  audio.beat = (float)std::exp(-sinceBeat * 6.0);
  audio.bpm = 120.0f;
}

}  // namespace

int main(int argc, char** argv) {
  const char* patternId = kDefaultPatternId;
  const char* host = "127.0.0.1";
  int port = 21324;
  double fps = 30;
  double seconds = -1;
  bool useFakeAudio = false;
  Params params;

  for (int i = 1; i < argc; i++) {
    const char* a = argv[i];
    if (std::strcmp(a, "--host") == 0 && i + 1 < argc) {
      host = argv[++i];
    } else if (std::strcmp(a, "--port") == 0 && i + 1 < argc) {
      port = std::atoi(argv[++i]);
    } else if (std::strcmp(a, "--fps") == 0 && i + 1 < argc) {
      fps = std::atof(argv[++i]);
    } else if (std::strcmp(a, "--seconds") == 0 && i + 1 < argc) {
      seconds = std::atof(argv[++i]);
    } else if (std::strcmp(a, "--fake-audio") == 0) {
      useFakeAudio = true;
    } else if (std::strchr(a, '=')) {
      char key[64];
      const char* eq = std::strchr(a, '=');
      const size_t klen = std::min((size_t)(eq - a), sizeof(key) - 1);
      std::memcpy(key, a, klen);
      key[klen] = '\0';
      const char* val = eq + 1;
      char* end = nullptr;
      const float f = std::strtof(val, &end);
      if (std::strcmp(val, "true") == 0) {
        params.setBool(key, true);
      } else if (std::strcmp(val, "false") == 0) {
        params.setBool(key, false);
      } else if (end && *end == '\0' && end != val) {
        params.setNum(key, f);
      } else {
        params.setStr(key, val);
      }
    } else {
      patternId = a;
    }
  }

  const Pattern* pat = findPattern(patternId);
  if (!pat) {
    std::fprintf(stderr, "unknown pattern '%s'. available:", patternId);
    for (int i = 0; i < kPatternCount; i++) std::fprintf(stderr, " %s", kPatterns[i]->id);
    std::fprintf(stderr, "\n");
    return 1;
  }

  const int sock = socket(AF_INET, SOCK_DGRAM, 0);
  if (sock < 0) {
    std::perror("socket");
    return 1;
  }
  sockaddr_in dst{};
  dst.sin_family = AF_INET;
  dst.sin_port = htons((uint16_t)port);
  if (inet_pton(AF_INET, host, &dst.sin_addr) != 1) {
    std::fprintf(stderr, "invalid host '%s' (use a literal IP)\n", host);
    return 1;
  }

  static uint8_t buffer[NUM_LEDS * 3];
  Geometry geo;  // default layout — must match the previewing server's layout
  AudioFrame audio;
  PatternCtx ctx{buffer, &geo, 0, 0, &audio, &params};

  std::printf("cube-native: pattern=%s -> %s:%d @ %.0ffps%s\n", pat->id, host,
              port, fps, useFakeAudio ? " (fake audio)" : "");

  const double t0 = nowSeconds();
  double lastT = 0;
  long frames = 0;
  if (pat->init) pat->init(ctx);

  while (true) {
    const double t = nowSeconds() - t0;
    if (seconds > 0 && t >= seconds) break;
    ctx.t = (float)t;
    ctx.dt = (float)(t - lastT);
    lastT = t;
    if (useFakeAudio) fakeAudio(audio, t);
    pat->render(ctx);
    sendFrame(sock, dst, buffer);
    frames++;

    const double nextT = t0 + frames * (1.0 / fps);
    const double sleepS = nextT - nowSeconds();
    if (sleepS > 0) usleep((useconds_t)(sleepS * 1e6));
  }

  std::printf("cube-native: sent %ld frames (%.1fs)\n", frames, nowSeconds() - t0);
  close(sock);
  return 0;
}

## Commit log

2026-07-06 Web + server prototyping environment for the LED cube
    Vite/React UI with 3D preview, calibration wizard, and pattern controls
    (port 5273); Express+ws+UDP server owning the pattern loop and DNRGB/DDP
    output to WLED (port 3037). 18 patterns in src/shared/ including audio-
    reactive wavy-sheet, snake/pacman games, and fireworks. Beads issue
    tracker state included.
    Claude-Session: https://claude.ai/code/session_0151mxWZZVPRx1twyeXuViXg
    [calibration.csv]
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2026-07-06 firmware: port rain, fire, comet
    Faithful translations of the TS patterns; dynamic arrays become fixed
    pools (512 drops, 256 comet particles — both above worst case). Adds
    shared frand() helper. All three verified against the DNRGB listener:
    fire fills the volume from a hot base, rain spans all z layers with
    trails, comet reads as a small bright splat cluster.
    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
2026-07-12 firmware: configurable LED pin/color order/button + current limiter
    Color order is now a runtime permutation (CUBE_COLOR_ORDER="RGB"/"GRB"/
    "BRG"...) applied when copying into the strip, so a wrong guess is a
    one-flag fix. cube_power adds a WLED-style auto brightness limiter:
    estimates frame draw from CUBE_PER_LED_MA (12V seed pixels ~15mA full
    white) and scales output to fit CUBE_SUPPLY_MA. Function button
    (CUBE_BUTTON_PIN, default GPIO0) short-press cycles patterns so the cube
    is usable with no network. Verified: full-white 15.5A frame scales to
    exactly a 10A budget; sparse frames pass through unscaled.
    Claude-Session: https://claude.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
    [main.cpp]
2026-07-12 firmware: on-chip web GUI, persisted settings, secured AP/OTA; ESP32 build verified
    The chip now serves a phone-friendly control page (pattern, brightness,
    power budget, color order) at http://cube.local/ and a /wifi page for
    network setup. Settings persist in NVS (Preferences); build flags are
    first-boot defaults only. The AP is WPA2 ("cube-light", password
    configurable) and the same password guards ArduinoOTA. mDNS as "cube".
    First full ESP32 compile (PlatformIO, esp32dev): initial link overflowed
    DRAM by 11KB, fixed by right-sizing the fireworks (768->320) and rain
    (512->320) pools. Final: RAM 35%, flash 68%. Native harness output
    unchanged after the pool shrink.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
    [main.cpp]
2026-07-12 Back up stock WLED config from the new 618WL; fix firmware pin defaults
    docs/wled-backup holds cfg.json (authoritative restore file) + settings
    screenshots from the factory WLED 0.15.3 at cube2-temp.local. Findings
    folded into the firmware defaults: function button is GPIO17 (not BOOT),
    color order GRB, and — critically — the energy-saving relay on GPIO18
    must be driven HIGH or the LED string has no power. main.cpp now raises
    it at boot. Mic documented as I2S PDM DATA=32 CLK=15 for the audio
    milestone. ESP32 build re-verified.
    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
    [main.cpp]
2026-07-12 firmware: dual LED output for the split-chain cube
    The 1000-LED chain will be cut at the wire midpoint and fed as two
    500-LED runs (GPIO16 = LEDs 0-499, GPIO12 = 500-999, concurrent RMT0/
    RMT1 transmission). Halves per-line transmit time (60fps ceiling) and
    data-error propagation. Geometry mapping is unchanged as long as the
    second half is fed at its original start, same wire direction — noted in
    the code. CUBE_LED_PIN2=-1 reverts to a single unbroken chain. Also
    clarified that GRB is the board's factory default, not the measured
    order of the actual string.
    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
    [main.cpp]
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2026-07-13 firmware: fix WiFi join crash-loop — upgrade to arduino-esp32 3.x
    Joining a WLAN as a client crash-looped the chip (InstructionFetchError
    in sta_recv_mgmt/offchan_recv_action) within seconds while AP mode ran
    fine — the arduino 2.x core's IDF 4.4 WiFi stack dies on 802.11k/v
    action frames from mesh routers. Bisected on hardware by eliminating
    the mic, RMT outputs, services, and rendering one flash at a time; the
    fix is the pioarduino platform (arduino-esp32 3.3.9 / IDF 5.5.4), which
    builds our source unchanged. Also restructured startup: network
    services + mic now start only after an interface is up, and rendering
    waits for net-up too. Verified on-device: joins SPot, survives, web
    API +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
    [audio_capture.cpp, main.cpp]
2026-07-13 firmware: /snake game pad, /api/game input, uptimeS; OTA path verified
    Guest-facing D-pad at /snake (6 directions, big touch targets, vibration
    tick) posting to /api/game, which routes to queueSnakeInput or
    queuePacmanInput per the active pattern. Both deliberately skip console
    auth so guests can play without the settings password. /api/status gains
    uptimeS for crash detection during soak testing.
    Milestone: this build was flashed OVER THE AIR (espota, auth) — first
    wireless update, USB now optional. Verified post-OTA: status, snake
    page, game endpoint, and pattern persistence across the reboot.
    Claude-Session: https://claude.ai/code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
    [main.cpp]
2026-07-13 bar-eq pattern, on-chip calibration wizard, which-way-is-up switch
    bar-eq (TS + C++): 5x5 grid of 2x2-footprint columns throbbing with the
    spectrum, lows-to-highs corner-to-corner along the diagonal, asymmetric
    attack/release, antialiased crests, classic green->red HSV fallback or
    palette by height/band.
    Calibration moves on-chip: cube_calibration ports the 8-flip solver with
    offset pinned by the first sample, plus the disambiguating-LED chooser
    rewritten around a closed-form inverse of the wire math (the lookup-table
    version overflowed ESP32 DRAM by 16KB). /calibrate wizard page drives
    lit-pixel via the new /api/param, collects hand-editable led,x,y,z
    samples, solves on-device, applies+per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
    [main.cpp]
2026-07-14 firmware: full settings console — per-pattern params, runtime LED config, nav, mic FIXED via IDF5 i2s_pdm driver
    Params: scripts/gen-param-specs.mts generates cube_param_specs.h from the
    TS pattern metas (19 patterns, 181 specs) so both sides share one source
    of truth. /api/params serves specs+values+palette list; the console
    renders sliders/selects/checkboxes per type, applies live via /api/param,
    and "Save as power-on defaults" persists per-pattern overrides to NVS
    (reloaded on pattern switch).
    LED outputs are runtime settings now: strips live on the heap, torn down
    and rebuilt by /api/ledcfg (pin1/pin2/split; pin2=-1 = single chain),
    persisted, applied without reboot. New default is a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
    [audio_capture.cpp, main.cpp]
2026-07-14 Guest/admin tiers, param resets, audio de-stutter + band decorrelation, per-bar EQ colors; drop plasma + day-cycle
    The console password now gates only the ADMIN tier (hardware, network,
    calibration, persistence — marked 🔒 and grouped); pattern picking, live
    params, brightness, and the game pad stay open so the cube can be handed
    to guests. New buttons: Reset to defaults (guest), Save as power-on
    defaults + Factory reset (admin).
    Audio fixes from field testing: the hard squelch gate snapped level/bands
    to zero whenever RMS dipped below threshold — the wavy-sheet stutter.
    Replaced with a soft-knee gate plus attack/release smoothing. Bands all
    moved as one mass because they shared the o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
    [audio_capture.cpp, main.cpp]
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2026-07-14 firmware: /leds page, live-stream banner, mic toggle lower, id-keyed params
    The "stuck on wavy-sheet" report was the forgotten Node dev server: a
    tsx-watch restart re-resolved cube.local (now the firmware's mDNS name)
    and streamed its default pattern via DNRGB, which the firmware yields to
    by design. The console now shows a warning banner whenever an external
    stream is overriding the local pattern (live flag in /api/status), so
    this diagnoses itself next time.
    LED output config moves to its own /leds page (nav everywhere). Mic
    reactivity toggle moves below the params section. Saved pattern params
    are now keyed by pattern id instead of registry index, so adding or
    removing patterns can't mis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
    [main.cpp]
2026-07-14 spiral + spin-cube patterns; snake defaults to auto with pad takeover; sparse defaults for rotating-planes
    Spiral: rectangular spirals with a guaranteed empty cell between arms
    (2-cell pitch), drawn head-first then unwound per layer, phase-delayed
    so the animation corkscrews up the cube, optional quarter-turn twist per
    layer. Spin-cube: a wireframe cube tumbling on two axes, edges drawn
    with trilinear splats, brighter corners, beat-kicked spin — deliberately
    sparse per the "selective lighting looks magical" principle. Both in TS
    and C++, verified via the native harness.
    Snake now defaults to auto (the BFS solver plays as a demo) and a game
    pad press flips it to manual — grab the control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
    [main.cpp]
2026-07-14 firmware: custom partition table — 1.875MB app slots (up from 1.25MB)
    The Arduino default table left the pattern catalog wedged at 92% of a
    1.25MB slot. This table (min_spiffs layout, made explicit) grows both OTA
    app slots to 1.875MB, dropping usage to 61%. NVS offset is unchanged, so
    the required one-time USB flash preserved every saved setting — verified
    on-device: pattern/up-axis/LED-pin/mic-toggle and WiFi creds all intact
    after reflash. OTA resumes with the larger slots.
    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
    [partitions_cube.csv]
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2026-07-20 Build Map: fix strand ends, add geometry-based axis mode
    Two corrections/additions from field feedback:
    - Strand mode now marks each strand's two ENDS (wire offset 0 and
    period-1: 0, 9/10, 19/20 …) — the physical folds — instead of the
    start + its neighbour. Middle markers centered on the true middle.
    - New "axis" mode (default): lights the two extreme planes and the two
    middle planes on a chosen axis via ctx.idx, so it follows the
    calibrated layout and highlights the actual cube faces. Better for
    verifying a layout / orienting the assembled cube.
    Calibrate page gains Mode + Axis selectors. Native-verified: strand
    cyan at 0,9,10,19,20…; axis-x two planes = 200 cyan + 200 a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
2026-07-21 Batch 2: /admin page, guest tinker mode, param-specs authoritative
    - web_ui.h + main.cpp: Admin controls (brightness/supply/color-order/mic
    config/save-power-on/factory/hardware links) moved off the main console
    to a new /admin page (auth-gated). Main page keeps pattern + params +
    reset. (cube-uua)
    - Guest "tinker" mode: isGuestRequest() flags clients on the SoftAP subnet
    as guests; /api/status exposes "guest". Owner-only endpoints (params/save,
    params/factory, miccfg, ledcfg, layout, POST /wifi, /admin, /leds,
    /calibrate) 403 for guests. Guests get a friendly banner + a cheeky
    "set it back" button that calls /api/params/reset (restores saved
    power-on defaults, never factory)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
    [main.cpp]
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2026-07-21 Batch 4: preset playlist — cycling, dwell, shuffle by priority, sidebar
    - main.cpp: PlaylistState + playlistTick() in loop() advances presets after
    each preset's dwellSec. esp_random() weighted shuffle (weight = priority
    1..5; priority 0 excluded from rotation), no immediate repeats. In-order
    mode plays all presets. Auto-pauses when the user changes pattern/param or
    loads a preset manually (playlistLoading guard prevents self-trip).
    - Endpoints: POST /api/playlist (enabled/shuffle; guest may pause only),
    /api/playlist/next|prev (owner), /api/presets/meta (edit dwell/priority),
    and /api/status now carries playlist {enabled,shuffle,current,dwellRemainingSec}.
    - web_ui.h: slide-ou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
    [main.cpp]
2026-07-21 Batch 5: preset import/export + rename (completes preset epic)
    - Export: GET /api/presets/export downloads the whole library as a bundle
    {version,presets:[...]}; ?name= exports one. Content-Disposition attachment.
    - Import: POST /api/presets/import reads the raw body (server.arg("plain")),
    accepts a bundle / bare array / single object, OVERWRITES presets with the
    same slug, respects kMaxPresets, returns {imported,overwritten,skipped}.
    - Rename: POST /api/presets/rename?from=&to= rewrites under the new slug,
    deletes the old file on slug change, updates live playlist.current.
    - cube_presets: exposed presetSlug() for slug-change detection.
    - web_ui.h: Export/Import controls + per-preset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
    [main.cpp]
2026-07-21 Batch 6: per-param modulation (LFO / random-walk), advanced feature
    - New firmware/src/cube_mod.h: ModStore applies auto-modulation to numeric
    params of the current pattern. pingpong = triangle scrub min<->max at
    `rate` units/s; walk = random +-`step` every 1/`rate`s (esp_random),
    clamped, bounces off edges. Ticked in loop() before render().
    - Endpoint POST /api/param/mod (owner-only; numeric params only); active
    mods surfaced inside GET /api/params as a per-spec "mod" object.
    - Persistence: NVS blob "pm<id>" alongside params, saved by
    /api/params/save, loaded on pattern change + reset, cleared by factory.
    Presets also carry a "mods" object (savePresetSnapshot/loadPresetByName).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
    [main.cpp]
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2026-07-21 Polish pass: spiral per-layer axis cycling, labeled+quantized mod inputs, preset sidebar rework
    - pat_spiral.cpp: "cycle" mode now derives each layer's axis from its OWN
    pass number instead of one global switch — trailing layers finish their
    spiral on the old axis while leading layers start on the new one, so the
    transition overlaps smoothly instead of yanking mid-unwind.
    - cube_mod.h: modulation entries carry the param's spec step as `quant`;
    written values snap to it (plane count only ever steps whole), with
    internal state kept continuous. Walk default step no longer spans the
    whole range on coarse params. main.cpp threads spec step into all three
    mods.set call sites.
    - web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
    [main.cpp]
2026-07-21 Adversarial sweep: fix 30+ verified findings across firmware + web UI
    Four independent review lenses (server C++, web UI/UX, guest/owner
    boundary, pattern math); all High/Medium findings fixed, cheap Lows too.
    Memory safety / crashes:
    - Mod bounds now clamp to the spec range at all entry points (endpoint,
    NVS blob load, preset load) — an out-of-range mod on fire.baseLayers
    wrote ~21KB past s_heat. Belt-and-braces upper clamps added in
    pat_fire (baseLayers<=N), pat_rotating_planes (planes<=4),
    pat_index_walk (tail<=50).
    - Params::setStr guards null (JSON as<const char*>() on non-string
    values panicked via strncpy on hand-edited preset imports); preset
    load also skips non-string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
    [main.cpp]
2026-07-31 Batch 8: preset shelves, game-pad shortcuts, OTA arming, wavy-sheet decay/edge params
    - Presets split into music-reactive vs ambient shelves (auto-classified,
    owner can toggle via the 🎵/🌙 marker); mic-off playlist cycles skip
    reactive presets (with fallback when only reactive ones exist).
    - Game pad gets 🐍/👾 quick-start buttons; the console shows a big
    'Grab the game pad' link whenever a game pattern is running.
    - Reflash prank-proofing: ArduinoOTA is disarmed by default and only runs
    in an owner-armed 15-minute window (/api/ota, admin page); arming refuses
    the factory-default AP password, and the WiFi page warns about it.
    - Wavy sheet: audioDecay param (fast-attack/slo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
    [main.cpp]
2026-07-31 Overnight batch: BPM tempo, tv-static + wander patterns, storm-cloud rework, param hover help, fire/life-3d removed
    - Audio engine: BeatDetector now tracks onset intervals and exposes a
    median-based BPM estimate (AudioFrame.bpm, 0 = no lock; stale after
    2.5s of silence). Shared audioSpeedMult() helper gives patterns a
    uniform speedFrom=none|level|bpm + speedGain knob. /api/audio reports
    bpm for on-hardware verification.
    - New pattern tv-static: black cube, random pixels flash white to the
    beat with R/G/B chromatic-aberration arms in distinct directions;
    beats stretch the arms; optional gray dead-channel background noise.
    - New pattern wander: index-walk grown into art — one bri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
    [audio_capture.cpp, main.cpp]
2026-07-31 Add gledopto309 env for the no-USB backup controller
    OTA-only board: first flash rides stock WLED's updater, so the build
    size-checks against WLED's factory 1.5MB app slots (partition table
    mirror in partitions_wled_4mb.csv). Relay/button disabled until the
    board's stock cfg.json is recorded.
    Claude-Session: https://claude.ai/code/session_01BFwKHPKWY3HDsdH3mL88wL
    [partitions_wled_4mb.csv]
2026-08-04 HA integration + shared audio throb: MQTT discovery, image-3d album art, text/spiral/tv-static upgrades
    - cube_throb.h: reusable beat-throb module with throbAttack/throbRelease
    smoothing (the raw 0.25s beat envelope read twitchy); snake-3d refactored
    onto it, text-3d and spiral gain the same three knobs via a shared
    CUBE_THROB_SPECS block.
    - text-3d: reverse now flips only the direction of travel — the char-to-slot
    mapping mirrors too, so the message no longer reads back-to-front.
    - tv-static: standard palette support — each glitch samples a random palette
    position; arms carry the color's channel split. "none" keeps the classic
    white/RGB look. (Custom user palettes filed as c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
    [ha_mqtt.h, main.cpp]
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2026-08-06 Snipped-LED compensation per output + intact-cube snip simulator
    Chains lose LEDs when burnt-out pixels get snipped off (the Reno cube
    already lost 1-2 at an unknown end). New per-output skip/trim settings
    (NVS, /api/ledcfg, /leds page) shift each data slot to the logical LED
    that physically sits there, so surviving LEDs keep calibrated geometry
    and snipped spots go dark. /api/ledsim (runtime-only, reboot clears)
    emulates a snipped chain on intact hardware to rehearse the settings.
    Applies in show(), so local patterns and DNRGB live frames both get it.
    Closes nothing; on-cube verification tracked as cube-1ka.
    [main.cpp]
2026-08-08 Single-color palette mode + audio-driven orbit count and size pulse
    Two shared additions to the pattern engine:
    - Palette "solo" mode (paletteSolo / soloSpeed) on every palette-bearing
    pattern. Instead of spreading the palette across the cube, the whole
    pattern takes one palette color per frame and drifts through the palette
    — "rainbow" walks the cube through the rainbow one color at a time.
    Implemented in the palette layer (resolvePalette bakes the drifting
    position into the PaletteRef, samplePalette ignores the per-voxel t), so
    all 19 palette patterns get it without touching their render bodies.
    Solo samples are renormalized to full value, since most gradients ramp
    out o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
    [main.cpp]
2026-08-14 Wander beat misprint, console power toggle, rail-grind + rez-tunnel patterns
    - wander: new beatAberration param — beats split the R/B channels off
    sideways along a random perpendicular axis (comic-misprint chromatic
    aberration), riding the beat envelope so it snaps out and settles back.
    Makes the audio reactivity legible on a pattern where it was subtle.
    - console: power soft-off/on button on cube.local (the HA light switch's
    /api/power endpoint existed but had no on-cube UI). Syncs with status
    polls, so HA and the console stay agreed.
    - new pattern rail-grind (prototype): first-person ride down a procedural
    neon rail, cube as viewport — camera heading chases the curve with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
2026-08-23 Console-password lockout fixes: block autofill, button-held-at-boot rescue
    The /wifi form's bare password inputs let a browser password manager
    autofill a saved credential on page load; the form-wide save then quietly
    persisted it as the console password — which gates /admin AND OTA arming,
    locking the owner out of their own cube with no software recourse.
    - All four password inputs (wifi, AP/OTA, console, MQTT) now carry
    autocomplete="new-password" + autocapitalize/autocorrect off.
    - New physical-access rescue: hold the function button through power-on
    for 3s to clear the console password. Active-low pullup, so a missing
    button can never trigger it.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
    [main.cpp]
2026-09-11 Playa fixes (0.5.0): AP guest toggle, persistent playlist, STA-retry parking, admin login prompts, text mirror
    Changes made on playa 2026-08-29..09-06 and flashed to both cubes, committed
    on return:
    - /wifi: "Hotspot visitors are guests" checkbox (apGuests). Unchecked, the
    WPA2 password is the only gate and AP clients get the full console.
    - Owner-only pages (/admin, /leds, /calibrate, /wifi) now *challenge* an
    unproven AP-subnet visitor with HTTP Basic auth instead of a dead-end 403.
    With no console password set, the AP/OTA password proves ownership
    (ownerPass()) so an owner on the fallback AP is never locked out.
    - Playlist on/off, shuffle and curated list persist in NVS (plon/pls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
    [main.cpp]
2026-09-11 Retire the React/Node WLED prototype; firmware is the sole source of truth
    Removes src/, server/, scripts/, the Vite/pnpm scaffolding and the server's
    calibration CSV. Everything is preserved at tag `wled-prototype` (the commit
    before this one). AGENTS.md rewritten for the firmware-only repo; firmware
    README loses its `pnpm dev:virtual` workflow (the native harness now points
    at a cube, stock WLED, or a future simulator); on-chip-plan.md marked
    historical; tmux dev window now opens a serial monitor + cube.local.
    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
    [calibration.csv]
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2026-09-11 bd export: playa-return triage — simulator epic, build-doc, 309 mic decision, I2S verification; 11 prototype-era issues closed
    Claude-Session: https://claude.ai/code/session_0132UkKzFUHnJgyLU26e5Yzi
2026-09-12 Backup cube is a GL-C-310WL (mic variant): correct docs, record live diag and flash plan
    cube2 /api/audio shows a constant -30935 sample under the PDM driver — a dead
    line, not a missing mic. The gledopto310 image (I2S 26/5/21) is the fix;
    flashing waits until 0.5.0 is proven on the USB-flashable 618 (cube-8p2).
    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
2026-09-13 Frame clips: v6 STLs (5/6-clip U and C), OpenSCAD source, print notes; build doc gets a Frame section
    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
    [comb-lib.scad, strut-c24.stl, strut-set.scad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]
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2026-09-16 Simulator round 2: playlist, onboarding modal, room light + neighbour spill, look prefs, Vercel config
    - Playlist: presets in the cube's export format (web/presets.json built-in,
    Import presets… stores the cube's /api/presets/export in localStorage).
    Cycles by default with per-preset dwell, skips music-reactive presets
    while audio is off, pauses on a manual pattern pick — same rules as the
    firmware. The wordmark shows the current preset's name unless typed over.
    - First-visit modal offers mic / synthetic beat / silent; choice remembered.
    - "Emulator look": collapsed by default with a hint that it only affects
    this page; every slider persists in localStorage; reset button.
    - Ref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
2026-09-16 Simulator: retro panel, mic nudge tag, portrait/square frames, tab audio, tighter room light
    - Panel restyled to match the tube: Righteous / VT323 / IBM Plex Mono via
    Google Fonts, amber phosphor text with glow, scanline overlay, bevelled
    console buttons, toggle-style checkboxes, sliders with a lit amber track
    up to the value and a single aligned knob.
    - "🎤 better with sound" tag over the tube whenever live audio isn't
    selected; click switches to the mic.
    - Capture folds into the (renamed) Emulator section with a Frame selector:
    full page, portrait 9:16, square, 16:9. The canvas letterboxes to the
    aspect so recordings come out reel-shaped; tall frames zoom the camera
    and rec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
